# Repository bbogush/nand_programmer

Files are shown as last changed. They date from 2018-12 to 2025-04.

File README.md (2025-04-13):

# NANDO (NANDopen) programmer

## THE PROJECT IS NOT ACTIVELY SUPPORTED

## General
NANDO is open source NAND programmer based on STM32 processor. It supports parallel NAND and SPI flash programming.

PCB boards:

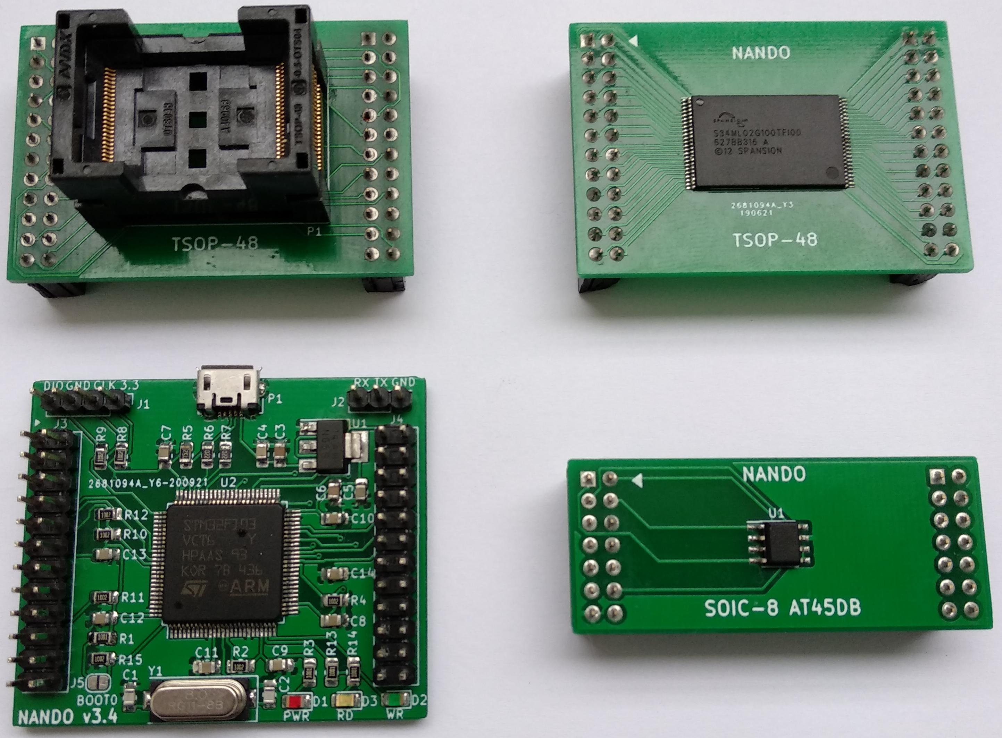
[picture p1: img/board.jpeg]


Application:

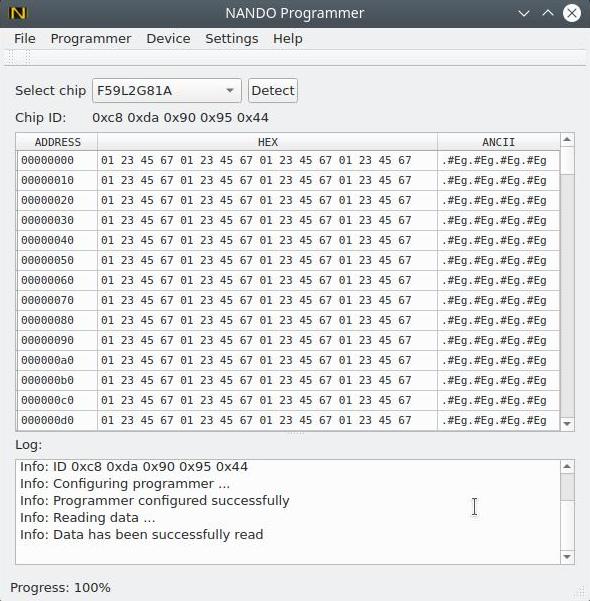
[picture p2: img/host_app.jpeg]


## Features
- USB interface
- PC client software for Linux & Windows.
- TSOP-48 socket adapter for NAND chip (compatible with TL866 adapter)
- TSOP-48 solder adapter for NAND chip
- 8 bit parallel NAND interface
- SPI interface
- 3.3V NAND power supply
- NAND read,write and erase support
- NAND read of chip ID support
- NAND read of bad blocks
- NAND bad block skip option
- NAND include spare area option
- Open KiCad PCB & Schematic
- Open source code
- Read & Write LEDs indication
- Extendable chip database
- Chip autodetection
- Firmware update

### Supported chips
#### Parallel NAND:
K9F2G08U0C, HY27US08121B, TC58NVG2S3E, F59L2G81A, MX30LF2G18AC and others.

See full list of supported chips [qt/nando_parallel_chip_db.csv](qt/nando_parallel_chip_db.csv)

#### SPI flash
AT45DB021D, MX25L8006E, W25Q16JV and others.

See full list of supported chips [qt/nando_spi_chip_db.csv](qt/nando_spi_chip_db.csv)

## Release binaries
You can download host application deb package for Ubuntu/Windows installer, firmware binary for
STM32, schematic and gerber files from <a href="https://drive.google.com/drive/folders/1d5hP6MKbkEBGQe_xIRl4-A5LPt_-9QIN">Google Driver</a>.

### License
In general the sorce code, PCB and schematic are under GPLv3 license but with limitations of:

firmware/libs/spl/CMSIS/License.doc

firmware/libs/spl/STM32_USB-FS-Device_Driver/ - http://www.st.com/software_license_agreement_liberty_v2

firmware/usb_cdc - http://www.st.com/software_license_agreement_liberty_v2

## WiKi
Check [WiKi](https://github.com/bbogush/nand_programmer/wiki) page for more information.

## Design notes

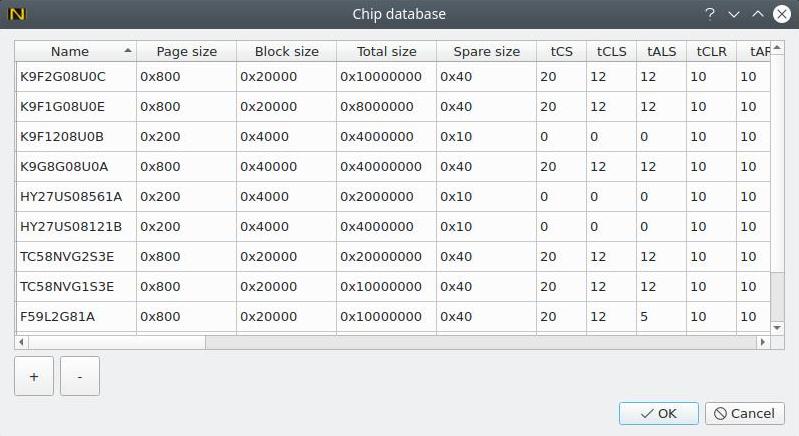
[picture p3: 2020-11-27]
img/chip_db_settings.jpeg

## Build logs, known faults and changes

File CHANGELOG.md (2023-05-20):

## [1.0.0] - 2018-11-25
- Initial release. Basic NAND operations support.
## [2.0.0] - 2019-03-09
### Added
- Reading of bad blocks.
- Skipping of bad blocks during read/write/erase.
- New PCB with smaller size, serial, LEDs and SWD instead of J-TAG.
- Firmware error codes.
- Firmware support of read and write LEDs.
### Fixed
- File-Save operation.
## [2.1.0] - 2019-04-16
### Added
- Chip database.
### Fixed
- Disconnect on the first connection.
## [2.2.0] - 2019-04-28
### Added
- Windows support.
- Added description of error codes.
### Fixed
- Fixed multiple prints of read ID completed log message.
## [2.3.0] - 2019-05-05
### Added
- Version support.
- Added progress indicator for erase, read and write commands.
### Fixed
- Fixed erase command.
- Fixed read bad block table command.
## [3.0.0] - 2019-09-26
### Added
- New board design. Support of internal clock in FW.
### Fixed
- Race condition in packet handling code.
## [3.1.0] - 2019-11-16
### Added
- Read including spare area
- Configuration of spare area size, number of column and row cycles, commands, bad block mark offset
- New chips support
- BOOT0 switch to PCB.
### Fixed
- Lost of some packets due to optimization.
## [3.2.0] - 2020-03-14
### Added
- Chip autodetection.
- Firmware update.
- Support of K9F1208U0B and F59L2G81A.
### Fixed
- Bad block table initialization.
- Read of bad blocks.
## [3.3.0] - 2020-08-31
### Added
- Single side components PCB 
- Support of HY27US08121B.
### Fixed
- Fixed read of bad blocks when read spare area command is available.
## [3.4.0] - 2020-12-22
### Added
SPI flash support.
SOIC-8 adapter for AT45DB.
New parallel NAND and SPI chips.
Boost library for serial port.
### Fixed
Fixed saving of settings.
Fixed lost of packets in Windows.
Fixed UI on Windows.
Schematic refactoring.
## [3.4.1] - 2021-02-14
### Added
Added NAND reset on init.
## [3.4.2] - 2021-03-17
### Added
Firmware compilation on Windows.
#### Fixed
Firmware update.
UI issues.
## [3.5.0] - 2023-05-20
### Added
Support of HW ECC.
Operation time estimate.
Serial port selector.
Progress indication.
Read/write to file instead of memory buffer.
Support of flash more then 4GB.
UI improvements for large buffers.
Custom read/write range.
Pinout table on PCB.
Verify operation.
### Fixed
NAND timings.
Synchronization issues.
Low write speed on Windows.

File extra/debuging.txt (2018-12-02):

debug (J-Link)
==============
1. Start openocd server:
# cd ~/dev/nand_programmer/nand_programmer/
# openocd -f extra/openocd.cfg
2. In new terminal connect to the server using telnet:
# telnet 127.0.0.1 4444
3. Reset board:
> reset halt
4. In new terminal start GDB:
# cd ~/dev/nand_programmer/
# compiler/gcc-arm-none-eabi-4_9-2015q1/bin/arm-none-eabi-gdb nand_programmer/firmware/obj/prog.elf
5. Connect to board:
>target remote localhost:3333
> b main
> continue

debug (ST-Link)
===============
1. Start st-util: 
# LD_LIBRARY_PATH=/usr/local/lib/ st-util
2. In new terminal start gdb
# cd ~/dev/nand_programmer/
# compiler/gcc-arm-none-eabi-4_9-2015q1/bin/arm-none-eabi-gdb nand_programmer/firmware/obj/prog.elf
> tar extended-remote :4242
> load
> b main
> continue

useful commands
===============
1. Disable pagination: 
> set pagination off
2. Print on breakpoint:
> break foo if x>0
     commands
     silent
     printf "x is %d\n",x
     cont
     end

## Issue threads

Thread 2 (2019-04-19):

USB device not found.

repairman0908, 2019-04-19:
serialprint:
NAND programmer ver: 2.1.0
JTAG init...done.
LED init...done.

I tested on win7 and showed unrecognized USB devices. What went wrong. Can you help me?

bbogush, 2019-04-19:
Hi repairman0908,
Do you have "USB init...done" and "CDC init..done" in the console log? If yes then USB initialization is done and probably you need driver for Windows. I will look for it and share a bit later.
In general the programmer should work out of the box on Ubuntu.

repairman0908, 2019-04-19:
Hello，bbogush，
Thank you for your reply！The following information is displayed only at power on or reset:
NAND programmer ver: 2.1.0
JTAG init...done.
LED init...done.
My circuit runs on the breadboard.

bbogush, 2019-04-19:
I can reproduce the same issue in 2 cases:
1. The driver is not installed. In this case you should see "STMMicroelectronics Virtual COM port" in Windows "Device Manager" as "Unknown device". I added official driver from STM to release folder  https://drive.google.com/drive/u/0/folders/1VHw-djlLal3cvaylapG-oUkLmzuEQM77
2. USB HW issue. The power connection is ok but no D+ & D-. You should check connection of mentioned lines from USB connector to MCU, also pull-up of D+ to 3.3V over 1.5R.

repairman0908, 2019-04-23:
Hi ,bbogush,
My board is working!   : )
I can read the chip ID.
But i received a error Msg : "programmer send error :104"  (when erase the chip.)

bbogush, 2019-04-24:
Hi,
Glad to hear you resolved USB issue.
The 104 error on erase means that programmer fails to read bad blocks from a NAND chip. Could you please provide more details about your setup?
In particular:
- Which NAND chip are you using? Is it  K9F2G08U0C?
- Which OS the program is running on? Is it Linux or Windows?

repairman0908, 2019-04-24:
Hi，bbogush,
Thank you for your patience.
1, the chip is  K9F1G08U0E.
2, The OS is Debian9 on virtual machine.
Do you have a windows program?

bbogush, 2019-04-24:
K9F1G08U0E is compatible with K9F2G08U0C which I've tested. So only "Size" should be adjusted in "Settings"->"Chip database" to 134217728 (128MB). Anyway the error is not related to this.
I am not sure it  works on virtual machine thereby better to check with normal OS. Currently there no version for Windows but I am working to provide it in the next release.
Usually the error 104 indicate HW issue. I would double check connection from MCU to NAND chip with multimeter according to schematic (test for continuity).
If you are using TSOP-48 socket it may be source of errors because it does not always provide reliable connection. A NAND chip should be clean and adjusted properly in socket.

bbogush, 2019-04-28:
Hi,
You can try initial version for Windows https://drive.google.com/drive/u/0/folders/1VHw-djlLal3cvaylapG-oUkLmzuEQM77. Windows 7/8 requires installation of driver. Also correct COM port need to be set in "Settings"->"Programmer".

bbogush, 2019-05-09:
Hi,
There are some pre-compiled binaries of CFE bootloader https://github.com/shsum/T3200M/tree/master/bcm963xx_router/targets/cfe. I am not sure which one is suitable for the router flash, maybe cfe63138rom.bin.
It looks the package contains only open source code so no guarantee it is compilable and run without proprietary part. I have tried as follows and it failed at some stage:
```
mkdir ~/dev
cd ~/dev/
git clone https://github.com/shsum/T3200M.git
sudo ln -s /home/<user>/dev/T3200M/toolchains /opt/toolchains
sudo ln -s /home/<user>/dev/T3200M/bcm963xx_router /opt/bcm963xx_router
 sudo apt-get install liblzo2-dev uuid-dev
cd ~/dev/T3200M/bcm963xx_router
make --trace PROFILE=963138BGW SHELL=/bin/bash
```

repairman0908, 2019-05-10:
Thank you for your help, I have tried all the CFE, they can not start my router.
There is also source code on the Netgear website. I don't know what is different. here[https://www.downloads.netgear.com/files/GDC/2649_GPLv1.html](url) Ctrl+f search v7610 can be found it.
Thank you very much!

bbogush, 2019-05-11:
Hi,
There is open source package for V7610.  The previous T3200M package was for different router based on the same Broadcom platform. It can be compiled similar to T3200M
"make PROFILE=V7610_TR181 SHELL=/bin/bash" but it also has compilation issues. Even if compiled I think it will not be functional because of missing proprietary code. There are also binaries for cfe you can try. You should have serial console connected to the router to see they work.
Also one of the methods is to clone flash from the same router.

repairman0908, 2019-05-12:
Hi,
Thanks for your advice. I used a serial console, but no information was printed. Because I can't find the same router, I just thought of compiling the source code. Anyway, thank you very much for your help.

bbogush, 2019-06-02:
As no other issues with the programmer I am closing it. If you have any other questions, please feel free to ask.

Closed 2019-06-02.

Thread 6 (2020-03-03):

STM32F103C8T6 porting

alexgrach, 2020-03-03:
Is it possible to port you project from STM32F103VCT6 to STM32F103C8T6?

bbogush, 2020-03-03:
The project requires FSMC (flexible static memory controller) which is embedded in the STM32F103xC, STM32F103xD and STM32F103xE family. Unfortunately, STM32F103C8T6 is missing this feature.

Closed 2020-03-03.

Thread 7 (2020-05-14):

Ask some questions

leovs, 2020-05-14:
Serial info：

NAND programmer ver: 3.1.0
JTAG init...done.
LED init...done.
USB init...done.
CDC init...done.
ERROR: NAND read bad block info error at 0x0

chip：ESMT  F59L2G81A

bbogush, 2020-05-14:
This error in most cases means bad hardware connection with NAND or NAND is broken. The sockets adapters are not usually provide reliable connection. It requires few tries to properly put NAND. To be sure I use soldering adapters. After soldering the adapter with NAND needs to be carefully cleaned from flux.
You can also try Settings -> Programmer -> Uncheck "Skip bad block" option in order to check that chip cannot be read.
Are you able to read correct chip ID - c8 da 90 95 44 ?
Have you compiled the latest source or used 3.1.0 release binaries?

leovs, 2020-05-14:
Thank you for your reply
Binaries used in version 3.1.0
chip ID ：0XFD 0XFD 0XFD 0XFD

leovs, 2020-05-14:
Nando running Windows 10
The default chip database does not have f59l2g81a
add :
F59L2G81A 0x800 0x20000 0x10000000 0x40 20 12 5 10 10 12 12 12 5 5 5 25 25 20 3 2 0x0 0x30 - 0x90 0xff 0x80 0x10 0x60 0xd0 0x70 0

leovs, 2020-05-14:
Uncheck "Skip bad block" option

info:"Bad block at 0x0XXXXXXXXXX size 0x00020000"
more
All failed

bbogush, 2020-05-14:
The latest code contains fixes and default support of f59l2g81a. I will make new release today so you can check.

bbogush, 2020-05-14:
The new 3.2.0 release of stm firmware and windows software is available for download.  Although SW contains fixes the chip ID 0XFD 0XFD 0XFD 0XFD in 99% shows NAND connection problem with programmer.

leovs, 2020-05-15:
Thank you
still:
Error: "Programmer sent error: (104) Failed to read chip"

maybe NAND connection problem，I'll check again

leovs, 2020-05-19:
It seems that the data can be read normally, but I don't know if it works correctly

Info: Connected to programmer
Info: Firmware version:  3.2.0
Info: Detecting chip ...
Info: ID 0xE8 0xFA 0xB0 0xB5 0x64
Info: Chip not found in database
Info: Configuring programmer ...
Info: Programmer configured successfully
Info: Reading data ...
Info: "Skipped bad block at 0x00000000 size 0x00020000"

bbogush, 2020-05-19:
There still problem with connection, the ID should be
0xC8 0xDA 0x90 0x95 0x44
but is
0xE8 0xFA 0xB0 0xB5 0x64
some pins are connected correctly but others not
0xC8 - 0b11001000
0xE8 - 0b11101000
Please check FSMC_D0 - FSMC_D7

bbogush, 2020-06-08:
Closing. Please reopen the issue if you still have any questions.
Regards

Closed 2020-06-08.

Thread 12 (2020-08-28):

Can you add support for spi nor flash chip？

jiuweiljp, 2020-08-28:
In the project https://github.com/dword1511/stm32-vserprog (libcopencm3) use STM32F103C8T6 PA4,5,6,7 to support spi nor flash

jiuweiljp, 2020-08-28:
old project https://github.com/dword1511/serprog-stm32vcp

bbogush, 2020-08-29:
Hi,
Thank you for idea. It is possible, but currently SPI pins are not routed. So this requires redesign of PCB. I will add it to work backlog but not sure it can be done soon.

Regards

jiuweiljp, 2020-08-31:
Thx, this would be really cool

jiuweiljp, 2020-08-31:
Thx, this would be really cool

alexgrach, 2020-12-07:
It would be nice to have I2C EEPROM support too...

bbogush, 2020-12-22:
Closing issue. SPI support added in version 3.4.0. I2C support may be added in next releases.

Closed 2020-12-22.

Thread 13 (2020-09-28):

Can show Effective(available) com port and put port select and connect  at  main window?

kuangjunchaos, 2020-09-28:
Can show Effective(available) com port and put port select and connect  at  main window?

port select         buttom
Com60 |             connect!
            V

bbogush, 2020-10-03:
Thank for idea, but I don't want to overload main window with multiple settings. This is not user friendly. The serial port should be configured once and usually it should be the same on the next connection. Currently settings are not saved but when this will be implemented selection of port should not be a problem.

Closed 2020-10-10.

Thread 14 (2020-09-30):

Reset button

alexgrach, 2020-09-30:
It would be nice to have reset button. I have to use a wire to reset before flashing over SWD by st-link.

bbogush, 2020-10-03:
HW reset button is rarely used and can be replaced by cable unplug-plug action. Thereby I would not add additional component to PCB design which may increase its size.

alexgrach, 2020-10-07:
I've added NRTS just like BOOT0 and made some changes in schematics to make it look better and readable.
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
[nand_programmator.zip](https://github.com/bbogush/nand_programmer/files/5343890/nand_programmator.zip)

Closed 2020-10-03.

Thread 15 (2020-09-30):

Windows binary version error

alexgrach, 2020-09-30:
I've just downloaded windows installer from google drive nando-3.3.0 folder. Help->About NANDO shows Version: 3.2.0
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

bbogush, 2020-10-03:
Updated. Thank you for notification.

Closed 2020-10-03.

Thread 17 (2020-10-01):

Error detecting TC58NVG1S3E

alexgrach, 2020-10-01:
I've tried to read 2 different NAND ICs. No success.

Info: Connected to programmer
Info: Firmware version:  3.3.0
Info: Detecting chip ...
Info: ID 0x8F 0x8F 0x8F 0x8F 0x8F
Info: Chip not found in database
Info: Detecting chip ...
Info: ID 0x8F 0x8F 0x8F 0x8F 0x8F
Info: Chip not found in database

bbogush, 2020-10-03:
In 99% it is hardware problem:
- no connection between STM and NAND, for example, some pins of STM are not soldered, NAND pins are not soldered or bad connection in TSOP socket.
- stray capacitance if flux is not cleaned well after soldering.

alexgrach, 2020-10-06:
I've resoldered my chip and it worked, thank you!
chip_db to support this IC:
`
TC58NVG1S3E, 2048, 131072, 268435456, 64, 20, 12, 12, 10, 10, 12, 12, 12, 5, 5, 5, 25, 25, 20, 3, 2, 0, 48, -, 144, 255, 128, 16, 96, 208, 112, 0, 152, 218, 144, 21, 118
`

bbogush, 2020-10-10:
Glad to hear it works for you.
Thank you for new chip. I've added it database.

Closed 2020-10-10.

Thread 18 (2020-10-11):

Reset pad

alexgrach, 2020-10-11:
I've added NRTS just like BOOT0 and made some changes in schematics to make it look better and readable.
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
[nand_programmator.zip](https://github.com/bbogush/nand_programmer/files/5343890/nand_programmator.zip)

_Originally posted by @alexgrach in https://github.com/bbogush/nand_programmer/issues/14#issuecomment-705198990_

bbogush, 2020-10-11:
I appreciate your contribution. The change looks really nice but currently I have some doubts whether to include it. The reason is that most programmers don't provide HW reset and I don't see use cases for it because this can be done by power off-on.

alexgrach, 2020-10-11:
I see. It seems to me that reset is needed when you update programmer FW from previous version (from 3.1 to 3.3 in my case). With new IC st-link does not ask to boot under reset. If you do like schematics I can delete reset pad (or you can do it) pcb won't suffer.

alexgrach, 2020-10-11:
[nand_programmator.sch.zip](https://github.com/bbogush/nand_programmer/files/5361173/nand_programmator.sch.zip)

bbogush, 2020-10-11:
I think now I understand. Sometime STM cannot be programmed because it has disabled SWD pins for some reason and the only way is too "connect under reset". The RST pads are required. Would you like to create git pull request with your original changes so you will be mentioned as project contributor by github? If not I can apply changes.

alexgrach, 2020-10-11:
I've never done this before but I'll try. #19

bbogush, 2020-10-12:
The changes are merged. Thank you for contribution.

Closed 2020-10-12.

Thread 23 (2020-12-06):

Can you add support for STM32F103ZET6

mlpzaq9998, 2020-12-06:
[1、STM32F103ZE核心板--原理图-1807M.pdf](https://github.com/bbogush/nand_programmer/files/5648222/1.STM32F103ZE.--.-1807M.pdf)

mlpzaq9998, 2020-12-06:
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

Run NANDO to display the （112）wrong data length

mlpzaq9998, 2020-12-06:
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

bbogush, 2020-12-06:
Hello,

I see STM32F103ZET6 should be compatible with NANDO's STM32F103VCT6.
Regarding error, the version of firmware was read correctly so USB communication works. The reason of error is that NANDO  firmware received not enough or to many data in configuration command. The UART log can show more information. Are you using released firmware and PC program provided in GoogleDriver?

mlpzaq9998, 2020-12-06:
using released PC program provided in GoogleDriver，The firmware is GitHub
How to eliminate errors?

bbogush, 2020-12-06:
The firmware and PC program should be the same version because communication protocol sometimes changes. So you should use the released PC program and firmware from google driver or checkout git tag of the same version, i.e, git checkout 3.3.0.

mlpzaq9998, 2020-12-06:
Use the same version of the checkout git tag，NANDO display

Info: Connected to programmer
Info: Firmware version: 3.3.0
Info: Detecting chip ...
Info: ID 0x8F 0x8F 0x8F 0x8F 0x8F
Info: Chip not found in database
Info: Detecting chip ...
Info: ID 0x8F 0x8F 0x8F 0x8F 0x8F
Info: Chip not found in database

It should be a hardware problem

mlpzaq9998, 2020-12-06:
Can the new firmware include HEX

bbogush, 2020-12-06:
0x8F 0x8F 0x8F 0x8F 0x8F pattern shows hardware problem - unconnected pins or high stray capacitance.

Yes, hex will be included, also it can be received by following conversion, but haven't tried if it works.
../../compiler/gcc-arm-none-eabi-4_9-2015q1/bin/arm-none-eabi-objcopy --input-target=binary --output-target=ihex obj/fw.bin obj/fw.hex

bbogush, 2020-12-22:
Closing old issues. Please reopen if you still have questions.

Closed 2020-12-22.

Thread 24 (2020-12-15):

How to flash firmware using usb serial cable?

bra1nslayer, 2020-12-15:
Hi,
I have FT232RL same board as here: https://www.sparkfun.com/products/12731
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

Is it possible to flash fimware nando_fw_v3_3_0.bin via arduino ide?Or another program suggestions?
Thanks in advance, very useful programmer btw.

bbogush, 2020-12-15:
Hi,
The best option is to use stlink programmer. You can try to use build-in USB/USART bootloader. For this you need to install stm32 tool https://www.st.com/en/development-tools/stm32cubeprog.html# and after that power on board with connected BOOT0 pins to load internal DFU bootloader. Though, I've just tried and this method for some reason does not work for me, device is not recognized by Windows.

bra1nslayer, 2020-12-16:
Hi,
Uploaded firmware using serial cable but neither windows and linux recognizes as usb device.For firmware upload i have used stm32cube for windows and stm32flash for linux.Writing firmware was successful but as i said it cannot detect as usb device.Here is some info:
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

```

[  409.635435] usb 1-4: new full-speed USB device number 2 using xhci_hcd
[  409.763420] usb 1-4: device descriptor read/64, error -71
[  409.999461] usb 1-4: device descriptor read/64, error -71
[  410.235499] usb 1-4: new full-speed USB device number 3 using xhci_hcd
[  410.363415] usb 1-4: device descriptor read/64, error -71
[  410.599495] usb 1-4: device descriptor read/64, error -71
[  410.707509] usb usb1-port4: attempt power cycle
[  411.363359] usb 1-4: new full-speed USB device number 4 using xhci_hcd
[  411.363514] usb 1-4: Device not responding to setup address.
[  411.571534] usb 1-4: Device not responding to setup address.
[  411.779727] usb 1-4: device not accepting address 4, error -71
[  411.911830] usb 1-4: new full-speed USB device number 5 using xhci_hcd
[  411.911947] usb 1-4: Device not responding to setup address.
[  412.120132] usb 1-4: Device not responding to setup address.
[  412.327371] usb 1-4: device not accepting address 5, error -71
[  412.327456] usb usb1-port4: unable to enumerate USB device
```
```
sudo stm32flash -w nando_fw_v3_3_0.bin -v -g 0x0 /dev/ttyUSB0

stm32flash 0.5

http://stm32flash.sourceforge.net/

Using Parser : Raw BINARY
Interface serial_posix: 57600 8E1
Version      : 0x22
Option 1     : 0x00
Option 2     : 0x00
Device ID    : 0x0414 (STM32F10xxx High-density)
- RAM        : 64KiB  (512b reserved by bootloader)
- Flash      : 512KiB (size first sector: 2x2048)
- Option RAM : 16b
- System RAM : 2KiB
Write to memory
Erasing memory
Wrote and verified address 0x08040000 (100.00%) Done.

Starting execution at address 0x08000000... done.
```
Thanks for help.

bbogush, 2020-12-17:
Hi,
The NANDO fw should print logs via USART1, so you can check if fw was written successfully.
Unfortunately cannot help with STM tool.

bra1nslayer, 2020-12-17:
Hi,
Just managed to work.I think microcontroller is executing code slow and failing to respond host pc.In meantime host was already giving up initing usb.
After flashing firmware i executed:
```
sudo stm32flash -g 0x08000000 /dev/ttyUSB0

stm32flash 0.5

http://stm32flash.sourceforge.net/

Interface serial_posix: 57600 8E1
Version      : 0x22
Option 1     : 0x00
Option 2     : 0x00
Device ID    : 0x0414 (STM32F10xxx High-density)
- RAM        : 64KiB  (512b reserved by bootloader)
- Flash      : 512KiB (size first sector: 2x2048)
- Option RAM : 16b
- System RAM : 2KiB

Starting execution at address 0x08000000... done.
```
Then dmesg shows usb is working properly.
```
[ 4287.735237] usb 1-4: USB disconnect, device number 103
[ 4292.787484] usb 1-4: new full-speed USB device number 104 using xhci_hcd
[ 4292.965180] usb 1-4: New USB device found, idVendor=0483, idProduct=5740, bcdDevice= 2.00
[ 4292.965185] usb 1-4: New USB device strings: Mfr=1, Product=2, SerialNumber=3
[ 4292.965188] usb 1-4: Product: STM32 Virtual COM Port
[ 4292.965190] usb 1-4: Manufacturer: STMicroelectronics
[ 4292.965192] usb 1-4: SerialNumber: 56F967703335
[ 4293.029379] cdc_acm 1-4:1.0: ttyACM0: USB ACM device
```
Entered nando gui:
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
But after powercycling i always have to execute "sudo stm32flash -g 0x08000000 /dev/ttyUSB0 "
Also tried to flash fimrware from gui app.Same behavior.
Tried powering up board externally first then connected 2 usb pins sometimes works.
BTW:What does 0xEF 0xEF means?
Thanks.

bra1nslayer, 2020-12-17:
Tried another chip id detection seems work:
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

bbogush, 2020-12-17:
Hi,
It looks that fw is loaded from RAM, not flash. Have you removed BOOT0 pins connection?
ID 0xEF ...means that NAND memory is not connected or some high stray capacitance (usually due to not cleaned flux).

bra1nslayer, 2020-12-17:
Yes i have removed BOOT0 after flashing firmware.Same behavior if i don't execute  stm32flash -g 0x08000000 it doesn't recognize usb.I didn't specify filename in ""sudo stm32flash -g 0x08000000 /dev/ttyUSB0 "" i think it runs on flash not RAM.As i said "Also tried to flash fimrware from gui app.Same behavior." i think it proves i doesn't run on RAM right?I have never used STM32 before so i may be mistaken.

bbogush, 2020-12-17:
Yes, the firmware is written to flash. STM has different boot modes - from flash/ram. I've just had assumption that for some reason it starts code execution from RAM and ```sudo stm32flash -g 0x08000000 /dev/ttyUSB0``` makes it execute code from flash. If you can see serial port logs from firmware before command than it is not the case. It can be USB issue.

bra1nslayer, 2020-12-17:
Ok i see now, let me explain step by step what i have done:

1-Attached usb serial to board
2-Executed putty in /dev/ttyUSB0
3-Powered on board (Plugged in USB cable)
4-No output from putty
5-Executed `sudo stm32flash -g 0x08000000 /dev/ttyUSB0` on linux terminal
6-This serial output from putty:
```

Start application: 0

NAND programmer ver: 3.3.0
JTAG init...done.
LED init...done.
```

Is this an indication of my usb connection is bad?

Thanks for helping.

bbogush, 2020-12-17:
3-Powered on board (Plugged in USB cable) - After this step there should be logs so probably STM boots from RAM/System memory.
LED init...done. - there should be other logs after this, so there is also usb problem but maybe it caused by this switching from RAM boot to flash boot.
You can check boot settings according to stm manual
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

bra1nslayer, 2020-12-17:
I think i must use st-link since i don't have one, will order it.Is type works fine?
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

bbogush, 2020-12-17:
V2 should be ok.

bra1nslayer, 2020-12-17:
Thanks, just bought it.Will post results.

bra1nslayer, 2020-12-21:
St-link didn't arrived yet but i managed to read a Hynix HY27US08281A, here is the parameters i have used:
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

In csv format:HY27US08281A, 512, 16384, 16777216, 16, 0, 0, 0, 10, 10, 35, 25, 20, 10, 10, 10, 50, 50, 30, 2, 1, 0, -, 80, 144, 255, 128, 16, 96, 208, 112, 0, 173, 115, -, -, -
In gui format:HY27US08281A 0x200 0x4000 0x1000000 0x10 0 0 0 10 10 35 25 20 10 10 10 50 50 30 2 1 0x0 - 0x50 0x90 0xff 0x80 0x10 0x60 0xd0 0x70 0 0xad 0x73 - - -
Could you please add to database?

bbogush, 2020-12-21:
Hi,
I've added HY27US08281A to the BD.
HY27US08281A has only two bytes of ID but programmer tries to read five for all chips, thereby ID is repeating. It is ok, only minor UI presentation issue.
The case looks great. Thanks!
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
bbogush, 2021-01-08:
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

According to datasheet HY27US08281A and HY27US08561A have different IDs so maybe ID was not correctly read.
HY27US08561A - ADh 75h
HY27US08281A - ADh 73h

bbogush, 2021-01-08:
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

Pins do not have pull-up/down so when unconnected their value undetermined.

bbogush, 2021-01-09:
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

Thank you for pointing this out. I was looking for this document to check.

danyhm, 2021-01-09:
I'm having problems reading a micron NAND flash

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

the part number is MT29F1G08ABAD which is very similar to MT29F4G08ABAD in it's parameters.

I can't get the programmer to detect the chip correctly. it's showing the above results

how can I start debugging this?

danyhm, 2021-01-09:
in fact having the NAND flash in the adapter or not doesn't make a difference in the results.

bbogush, 2021-01-09:
> also the pcb design is not the best. R2 is chosen as 10k which is too much and my board keeps resetting. i changed it to 1.5k and now the reset problem is solved

The general problems are:
- TSOP-48 socket does not provide reliable connection for unsoldered NAND because pins are not even so advise is use "soldering adapters", try to adjust NAND in socket to see the difference in read ID.
- no connection between MCU and adapter/NAND, try to check connections by tester.
- stay capacitance, make sure no flux leftovers after soldering.

danyhm, 2021-01-09:
after connecting and disconnecting all the wires I could get the first byte correct

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

but still no success

danyhm, 2021-01-09:
ok i managed to get it working. it seems to be a software issue.

I added the new chip in the parallel database and configured it according to the datasheet which is exactly the same as MT29F4G08ABAD except the chip ID is `0x2c 0xf1 0x80 0x95 0x02` and the total size is `0x8000000`

normally clicking detect gives the wrong output like
```
Info: Detecting chip ...
Info: ID 0x2c 0x01 0x02 0x03 0x04
Info: ID 0xff 0xff 0xff 0xff 0x00
```
but if I select the chip manually and then click read , the chip is read. afterwards clicking detect gives the correct result
also when clicking read sometimes it gives the error `Error: Chip size is not set` while it actually is set in the database. but changing the totalsize to something else then solves the error and the chip can be read.

i hope I was clear in explaining the bug

danyhm, 2021-01-11:
just a question out of the topic.

I'm trying to restore my scope which firmware I corrupted by accident. I'm programming the bootloader after erasing the first block but after soldering the Nand it still doesn't boot. what could I be doing wrong? could it have to do something with the OOB data part? should that be cleared too ?

bbogush, 2021-01-11:
> just a question out of the topic.
>
> I'm trying to restore my scope which firmware I corrupted by accident. I'm programming the bootloader after erasing the first block but after soldering the Nand it still doesn't boot. what could I be doing wrong? could it have to do something with the OOB data part? should that be cleared too ?

I don't have MT29 to check but other chips work correctly. Have you verified that write was successful by comparing write and read dump? I still recommend to make soldering adapter to avoid any hw issues. OOB data should be already cleared by block erase because there is no separate command for OOB erase. The best approach to recover bootloader is to have dump from working device together with OOB.

danyhm, 2021-01-11:
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

yes I compared the written data with another read and the write has been successful. I have a dump of a working device but it doesn't have OOB data. I'm scratching my head here as logically it should work, but it's not working. :(

danyhm, 2021-01-12:
I think i have a lead.

The Zynq 7000 series in my oscope uses internal ECC feature of the Nand flash.
Since I'm programming with ECC disabled (default on POR) the OOB data doesn't include the parity bits generated by internal ECC and that might be why the bootloader is failing.

Nando software doesn't support enabling internal ECC yet , so I have 2 options
1- Implement the ECC feature my self. but I'm not familiar with the code flow and it takes a lot of time.
2- manually calculate the ECC parity bits and add them in OOB data and program with those.

do you know how the parity Bits are calculated ?
it would be very neat if you could add a custom command window where one can send and receive custom data to the chips.

bbogush, 2021-01-12:
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

Good catch! I cannot help with ECC calculation but it's required feature and will think how to add it future.

danyhm, 2021-01-12:
thank you very much,
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

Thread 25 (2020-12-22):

Can you add support for stm32 blue pill ?

ellissonmax, 2020-12-22:
I am trying read/write on hy27uf084g2b with a stm32 (Blue Pill).

ellissonmax, 2020-12-22:
> stm32flash -g 0x8000000 -w nando_fw_v3_4_0.bin /dev/ttyUSB0

 stm32flash 0.5

 http://stm32flash.sourceforge.net/

 Using Parser : Raw BINARY
 Interface serial_posix: 57600 8E1
 Version      : 0x22
 Option 1     : 0x00
 Option 2     : 0x00
 Device ID    : 0x0410 (STM32F10xxx Medium-density)
 - RAM        : 20KiB  (512b reserved by bootloader)
 - Flash      : 128KiB (size first sector: 4x1024)
 - Option RAM : 16b
 - System RAM : 2KiB
 Write to memory
 Erasing memory
 Wrote address 0x08020000 (50.00%) Done.

 Starting execution at address 0x08000000... done.

Closed 2020-12-22.

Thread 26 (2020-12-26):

Does it support STM32F407?

quanghau113, 2020-12-26:
I have a STM32F407 board. Can I make it work on STM32F4 series?

bbogush, 2020-12-26:
STM32F407 supports all required hardware features (FSMC, SPI, USB) but software supports only STM32F103 family (256-512MB flash).

enilfodne, 2021-01-22:
On that note, would you be willing to merge a PR for STM32F2/4 support?

It's a big PR (very hard to split up in smaller commits) and the scope is software-only (i.e. no new schematics or part-numbers).

bbogush, 2021-01-27:
> On that note, would you be willing to merge a PR for STM32F2/4 support?
>
> It's a big PR (very hard to split up in smaller commits) and the scope is software-only (i.e. no new schematics or part-numbers).

I suggest to merge support of STM32F4 to separate branch such as support_stm32f4 and it may be integrated to master in future.

bbogush, 2021-02-28:
Closing old issues. Please reopen if open questions remain.

Closed 2021-02-28.

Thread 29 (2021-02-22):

The Qt host application will not compile on gcc9 and newer

nQ1PX, 2021-02-22:
Similar to #8 and still 100% reproducible on my system on the latest commit. Additionally, removing `-Wextra -Werror` in `qt.pro` has no effect, as you can see they still show up in the output. I have tested gcc6 all the way to gcc10, gcc8 is the last version that will build the host application.

```
$ make
/../lib64/qt5/bin/uic main_window.ui -o ../build/ui/ui_main_window.h
/../lib64/qt5/bin/uic parallel_chip_db_dialog.ui -o ../build/ui/ui_parallel_chip_db_dialog.h
/../lib64/qt5/bin/uic settings_programmer_dialog.ui -o ../build/ui/ui_settings_programmer_dialog.h
/../lib64/qt5/bin/uic about_dialog.ui -o ../build/ui/ui_about_dialog.h
/../lib64/qt5/bin/uic firmware_update_dialog.ui -o ../build/ui/ui_firmware_update_dialog.h
/../lib64/qt5/bin/uic spi_chip_db_dialog.ui -o ../build/ui/ui_spi_chip_db_dialog.h
g++ -c -pipe -std=c++11 -O2 -Wall -Wextra -D_REENTRANT -fPIC -DQT_NO_DEBUG -DQT_WIDGETS_LIB -DQT_GUI_LIB -DQT_CORE_LIB -I. -I/usr/include/qt5 -I/usr/include/qt5/QtWidgets -I/usr/include/qt5/QtGui -I/usr/include/qt5/QtCore -I../build/moc -I../build/ui -I/../lib64/qt5/mkspecs/linux-g++ -o ../build/o/unix/main.o main.cpp
In file included from writer.h:9,
                 from programmer.h:12,
                 from main_window.h:9,
                 from main.cpp:6:
cmd.h:122:13: error: flexible array member ‘RespHeader::data’ not at end of ‘struct<unnamed>’
  122 |     uint8_t data[];
      |             ^~~~
cmd.h:128:15: note: next member ‘FwVersion <unnamed struct>::version’ declared here
  128 |     FwVersion version;
      |               ^~~~~~~
cmd.h:126:1: note: in the definition of ‘struct<unnamed>’
  126 | {
      | ^
cmd.h:122:13: error: flexible array member ‘RespHeader::data’ not at end of ‘struct<unnamed>’
  122 |     uint8_t data[];
      |             ^~~~
cmd.h:134:12: note: next member ‘ChipId <unnamed struct>::nandId’ declared here
  134 |     ChipId nandId;
      |            ^~~~~~
cmd.h:132:1: note: in the definition of ‘struct<unnamed>’
  132 | {
      | ^
cmd.h:122:13: error: flexible array member ‘RespHeader::data’ not at end of ‘struct<unnamed>’
  122 |     uint8_t data[];
      |             ^~~~
cmd.h:140:14: note: next member ‘uint32_t <unnamed struct>::addr’ declared here
  140 |     uint32_t addr;
      |              ^~~~
cmd.h:138:1: note: in the definition of ‘struct<unnamed>’
  138 | {
      | ^
cmd.h:122:13: error: flexible array member ‘RespHeader::data’ not at end of ‘struct<unnamed>’
  122 |     uint8_t data[];
      |             ^~~~
cmd.h:147:14: note: next member ‘uint32_t <unnamed struct>::ackBytes’ declared here
  147 |     uint32_t ackBytes;
      |              ^~~~~~~~
cmd.h:145:1: note: in the definition of ‘struct<unnamed>’
  145 | {
      | ^
cmd.h:122:13: error: flexible array member ‘RespHeader::data’ not at end of ‘struct<unnamed>’
  122 |     uint8_t data[];
      |             ^~~~
cmd.h:153:13: note: next member ‘uint8_t <unnamed struct>::errCode’ declared here
  153 |     uint8_t errCode;
      |             ^~~~~~~
cmd.h:151:1: note: in the definition of ‘struct<unnamed>’
  151 | {
      | ^
cmd.h:122:13: error: flexible array member ‘RespHeader::data’ not at end of ‘struct<unnamed>’
  122 |     uint8_t data[];
      |             ^~~~
cmd.h:159:14: note: next member ‘uint32_t <unnamed struct>::progress’ declared here
  159 |     uint32_t progress;
      |              ^~~~~~~~
cmd.h:157:1: note: in the definition of ‘struct<unnamed>’
  157 | {
      | ^
make: *** [Makefile:639: ../build/o/unix/main.o] Error 1
```

bbogush, 2021-02-28:
Fixed, removed flexible array usage.

Closed 2021-02-28.

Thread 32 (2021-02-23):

Potential issues on bad block handling

nQ1PX, 2021-02-23:
I was testing a few chips I happened to have on hand and preparing to send in a PR, but I noticed the current bad block handling strategy might not be the best here. Suppose I have a 128MB chip with 4 bad blocks, the read result does not correlate to the actual data on flash, as I have 0x80000 of 0x00 at the very end of the buffer.

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

And if I load a 128MB file, the write operation will cause the program to error out too, because my file was "too large" if you subtract the 4 bad blocks.
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

Usually the "skip bad block" option in other things I've seen just increments the counter and skips the actual r/w operation, so fill bad blocks with FF in buffer for read and skipping writing/erasing entirely (discard data for bad blocks). This way we can still have a consistent, whole 128MB file without having to worry about manually recording the offsets and mangling with the binary with a hex editor to insert/remove blank bits.

bbogush, 2021-03-13:
Fixed. Skipped bad block are not included in read buffer.

Closed 2021-03-13.

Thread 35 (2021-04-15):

Fix ASCII typo (?) in GUI

donnm, 2021-04-15:
The third column in the GUI shows printable ASCII bytes, but is named ANCII. I assume this is a typo?

bbogush, 2021-04-16:
Thank you for noticing. Fixed.

Closed 2021-04-16.

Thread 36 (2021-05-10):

Replace R3, R13, R14 with lower value resistors

donnm, 2021-05-10:
The LEDs are quite dim under normal ambient room lighting. I have built a few of these boards now and through experimentation found that from 100R to 330R are a more suitable brightness. For what its worth I spec'd the LEDs directly from the part numbers in the BOM.

You might consider replacing R3, R13, and R14 with lower value resistors in the HW design.

bbogush, 2021-06-21:
Thanks for sharing. I will consider changes.

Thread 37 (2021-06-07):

Parallel NOR flash support?

donnm, 2021-06-07:
I started adding support for M29W640GB in the chip database before realising it was NOR flash (couldn't find all the timing info in the datasheet). Does this have any chance of working?

bbogush, 2021-06-08:
Currently NOR is not supported, I think it will not work because NOR uses different programming approach.

gitercn, 2021-06-20:
I'm also looking for a programmer for Spansion S29 NOR FLASH programmer (TSOP56). Is there any open source NOR programmers? Could this project add NOR support?

bbogush, 2021-06-21:
> I'm also looking for a programmer for Spansion S29 NOR FLASH programmer (TSOP56). Is there any open source NOR programmers? Could this project add NOR support?

I haven't seen open source NOR programmers. This project can be extended to support NOR and STM chip has support of it. I'm not sure when it will be added because development requires some time.

donnm, 2021-06-21:
There's this, an Arduino Mega connected to a 32 pin PDIP NOR flash: https://mint64.home.blog/2018/07/29/parallel-nor-flash-eeprom-programmer-using-an-arduino-part-1-the-sst39sf040-and-planning/

Part 2 has the Arduino sketch code: https://mint64.home.blog/2018/07/30/parallel-nor-flash-eeprom-programmer-using-an-arduino-part-2-arduino-code-and-serial-comms/

Closed 2023-05-23.

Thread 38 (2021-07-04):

Porting programmer to raspberry

hamid1920, 2021-07-04:
Is it possible to add support for raspberry boards
It has all needed pins so there is no need to build a programmer pcb from scratch

bbogush, 2021-07-04:
MCU should have some memory interface as FSMC in STM. Otherwise read/write of NAND using GPIO bit-banging will take hours. I see raspberry pi has SMI (secondary memory interface). Need to do proof of concept to see whether it is suitable.

Closed 2023-05-23.

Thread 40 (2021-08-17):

TSOP56 NAND Compatibility

kooroshi60, 2021-08-17:
Does NANDO support 56 pin NAND memories? If so, how is the pin assignment on the 48pin socket ?
I would be happy to design and share the PCB for such an adapter if it is possible.

bbogush, 2021-08-21:
TSOP-56 is usually used by NOR memories. I've checked few websites with parts and haven't found 56 pin NAND. NOR currently is not supported because it requires change of MCU to another model with more pins.

kooroshi60, 2021-08-22:
Thank you so much for your informative answer.

Closed 2021-08-22.

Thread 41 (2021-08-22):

NANDO Eagle PCB (48pin ZIF)

kooroshi60, 2021-08-22:
Here is an another variant of PCB for this great project. (Eagle 9 Format + PDF)
-Since the track clearance is .15mm, this PCB has to be made with Photo Resist film technic.
Toner transfer method is not precise enough.
-This is a double layer PCB so don't forget to solder VIAs.
-All the components except the USB connector are SMD.
-You can find the value of the components in the Eagle files.
-You can either use a 48pin ZIF IC Socket or 4 rows of pin headers in order to support 7.2mm and 15.24mm ZIFs.
-There are 18 pins of the socket which need a VIA wire. Other pins of ZIF socket and the USB connector are routed from Bottom layer.
[NANDO Bottom.pdf](https://github.com/bbogush/nand_programmer/files/7027975/NANDO.Bottom.pdf)
[NANDO TOP.pdf](https://github.com/bbogush/nand_programmer/files/7027976/NANDO.TOP.pdf)
[Nando_ZIF48_USBb.zip](https://github.com/bbogush/nand_programmer/files/7027980/Nando_ZIF48_USBb.zip)

bbogush, 2021-08-28:
Thanks for sharing ZIF schematic.
VET6 and VDT6 should also work, the redundant memory will not be used.

kooroshi60, 2021-12-24:
And here is a picture of completed Nando programmer. Many thanks to Mr. Bogus
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
h

bbogush, 2021-12-25:
Very nice PCB. Thank you!

ucsoom, 2023-03-19:
I created a programmer like yours based on your PCB file. The trouble now is that I have searched the internet for a suitable hex file for this programmer. Could you please send the hex file of your programmer? My email address is 401707682@qq.com

ucsoom, 2023-03-19:
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

bbogush, 2023-03-19:
@ucsoom all hex files are located on Google driver https://drive.google.com/drive/folders/1AGWV5_WANd6tItfXJFq4AlQePkRsusNU

ucsoom, 2023-03-20:
Thank you! Open Google's website here in China.

ucsoom, 2023-03-20:
Thank you! China has banned Google.

ucsoom, 2023-03-20:
The website you sent cannot be accessed

whitcloudfly, 2024-04-29:
可以用STM32cubeide开发hal库的固件，移植难度很小。

ucsoom, 2025-04-03:
My programmer doesn't know why, the Tsop48 chip is connected to the programmer, the programmer can't recognize it, and the Tsop48 chip programmer can recognize it. Can you help me?

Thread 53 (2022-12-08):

Does it support GD32F103VCT6?

myseil, 2022-12-08:
Hi！
I have a GD32F103VCT6 chip, can use it to replace STM32F103VCT6?

myseil, 2022-12-09:
GD32F103VCT6 is determined to be available and can replace STM32F103VCT6

myseil, 2022-12-20:
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
I'm sorry! Using GD32F103VCT6 does not work properly, and the data written is not consistent. I don't know where this is the problem! Attached is the [GD32F103VCT6 datasheet](https://cdn.jsdelivr.net/gh/myseil/PicGoCDN@master/img/GD32F103xxDatasheet_Rev2.12.pdf)

myseil, 2022-12-20:
The main frequency of GD32F103VCT6 is higher than that of STM32F103VCT6, is this the reason?

alexgrach, 2022-12-20:
GD32F303VCT6 is used intead of STM32F103VCT6 in 3d printer boards

myseil, 2022-12-22:
> GD32F303VCT6 is used intead of STM32F103VCT6 in 3d printer boards

？？？

ssp97, 2023-05-16:
https://oshwhub.com/myseil/nandopen
In this article, it is proven that GD32F103 is binary compatible with STM32F103.

myseil, 2023-05-17:
>

This project was created by me and can not be used with GD32!

ssp97, 2023-05-17:
> >
>
> This project was created by me and can not be used with GD32!

Yes. I saw in your article that it was written, "The program can be directly flashed following the original author's steps, just by replacing the STM tools with GD tools, it's quite simple."(程序按照原作者的步骤直接刷，就是STM的工具换成GD的工具，很简单) That's why I believed that running it on GD32 has already been achieved.

myseil, 2023-05-18:
>

emmm！立创的这个项目也是我搬过去的，也是用的GD工具刷的，然后和STM的进行对比验证，会发现数据不一致！

bbogush, 2023-05-23:
GD32 is not supported. Closing issue.

Closed 2023-05-23.

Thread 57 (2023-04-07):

Porting to stm32F407 series?

deividAlfa, 2023-04-07:
These are even cheaper than the stm32f103, while way faster, also cheap development boards can be found everywhere, while the 100pin f103 is not commonly found.
Would it be very hard to add support for it?

Cheers

bbogush, 2023-05-23:
Thanks for idea! Unfortunately effort developing new board and adding support is big. No plans for this now.

Closed 2023-05-23.

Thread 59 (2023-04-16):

Is K9F1G08U0D supported?

hpznot, 2023-04-16:
I added the K9F1G08U0D chip, but there was an warning:"Warning: QXcbConnection: XCB error: 3 (BadWindow), sequence: 14950, resource id: 13199545, major code: 40 (TranslateCoords), minor code: 0". And The following prompt appears when I connect.
"Info: Detecting chip ...
Info: ID 0xcf 0xcf 0xcf 0xcf 0xcf
Info: ID 0x80 0x80 0x80 0x80 0x02
Info: Chip not found in database
Error: Chip size is not set
Error: Chip size is not set
Info: Chip page size is unknown
Info: Reading bad blocks ...
Info: Bad blocks have been successfully read"
The above operations are detected,erased,read,written and read bad blocks in sequence.
[K9F1G08U0D-Samsung.pdf](https://github.com/bbogush/nand_programmer/files/11241958/K9F1G08U0D-Samsung.pdf)

deividAlfa, 2023-04-16:
Check
https://github.com/bbogush/nand_programmer/blob/master/qt/nando_parallel_chip_db.csv

Add a new entry for your chip.

hpznot, 2023-04-16:
> It seems supported: https://github.com/bbogush/nand_programmer/blob/master/qt/nando_parallel_chip_db.csv
>
> However your ids seem strange. Maybe a bad connection?

The chip is soldered. I have also tried changing the chip, but it still doesn't work.

hpznot, 2023-04-19:
I found that I still have the same problem using K91G08U0E. Why is this?

hpznot, 2023-04-19:
Can 1117 output 3.28V be used?

> It seems supported: https://github.com/bbogush/nand_programmer/blob/master/qt/nando_parallel_chip_db.csv
>
> However your ids seem strange. Maybe a bad connection?

Can 1117 output 3.28V be used?

deividAlfa, 2023-04-19:
The list has the K9F2G08U0A& M parts, but not the D, each one has a different ID.
The "D" ID is ```EC F1 00 95 40```

# name	page size	block size	total size	spare size	bad block mark off.	tCS	tCLS	tALS	tCLR	tAR	tWP	tRP	tDS	tCH	tCLH	tALH	tWC	tRC	tREA	row cycles	col. cycles	read 1 cycle com.	read 2 cycle com.	read spare com.	read ID com.	reset com.	write 1 cycle com.	write 2 cycle com.	erase 1 cycle com.	erase 2 cycle com.	status com.	set feat. com.	en. ECC addr	en. ECC val.	dis. ECC val.	ID1	ID2	ID3	ID4	ID5

K9G8G08U0D	2048	262144	1073741824	64	0	20	12	12	10	10	12	12	12	5	5	5	25	25	20	3	2	0	48	-	144	255	128	16	96	208	112	-	-	-	-	236	241	00	149	64

Closed 2023-05-23.

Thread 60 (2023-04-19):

K9K2G08U0M SLC Die Stack series support

loki-amorf, 2023-04-19:
Is any big difference in work logic between K9K2G08U0M and K9F2G08U0B for example?

My quick research third symbol meaning
F : SLC Normal
K : SLC Die Stack
some of SLC Die Stack chips have 2 chip enable pin CE0/CE1 and CE0 but K9K2G08U0M has only one CE

bbogush, 2023-05-23:
No big difference, maybe some timing parameters. K9K2G08U0M is 1.8V which is currently not supported.

Closed 2023-05-23.

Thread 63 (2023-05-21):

Hangs 3.5.0

Sana956, 2023-05-21:
Ver.  3.5.0
Hangs when writing on the second BB.

(Info: "Bad block at 0x0035a840 size 0x00021000"
Info: "Bad block at 0x0035b080 size 0x00021000")
K9F1G8U0E

Doesn't work either - "Read bad blocks":
(Error: "Programmer sent error: (104) Failed to read chip")

Everything else works.
Windows 10 64x

bbogush, 2023-05-21:
Thanks for trying new firmware. I cannot reproduce reported issue on my board. Error 104 is reported when there is hardware communication problem between STM and NAND. Bad block on write also points to this.

v6760hu, 2023-05-23:
可以弄个GD32F103VCT6 的固件吗  STM32F103VCT6  快

Closed 2023-05-23.

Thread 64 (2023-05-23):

可以弄个GD32F103VCT6 的固件吗 STM32F103VCT6 快

v6760hu, 2023-05-23:
主频也比 STM32F103VCT6 高  而且还提升了写入速度

bbogush, 2023-05-23:
Thanks for idea! Looks GD32F103VCT6 is good low price alternative. Unfortunately developing new board and adding support is big effort even if they looks similar. No plans for this now.

v6760hu, 2023-08-05:
stm32f407vet

?凡事↗都飞
***@***.***

&nbsp;

------------------&nbsp;原始邮件&nbsp;------------------
发件人:                                                                                                                        "bbogush/nand_programmer"                                                                                    ***@***.***&gt;;
发送时间:&nbsp;2023年5月24日(星期三) 凌晨4:04
***@***.***&gt;;
***@***.******@***.***&gt;;
主题:&nbsp;Re: [bbogush/nand_programmer] 可以弄个GD32F103VCT6 的固件吗 STM32F103VCT6 快 (Issue #64)

Thanks for idea! Looks GD32F103VCT6 is good low price alternative. Unfortunately developing new board and adding support is big effort even if they looks similar. No plans for this now.

—
Reply to this email directly, view it on GitHub, or unsubscribe.
You are receiving this because you authored the thread.Message ID: ***@***.***&gt;

Closed 2023-05-23.

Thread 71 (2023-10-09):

Issue with EN25F80-75HCP

kooroshi60, 2023-10-09:
I noticed that Nando programmer can't read the device ID of this particular chip. I tested 3 devices with same result. I was wondering if anyone has experienced such an issue?

Jichao, 2023-10-14:
any error message?

kooroshi60, 2023-11-10:
There is no any error messages. Programmer detects a wrong ID and in result the SPI chip is unrecognizable.

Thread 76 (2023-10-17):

准备把nando用STM32CubeMX和STM32CubeIDE移植到STM32F407VET6的HAL库上。bootloader和app的cdc驱动已做好了。有兴趣可以一起加入

whitcloudfly, 2023-10-17:
准备开发带触摸屏的脱机烧写的版本。

whitcloudfly, 2023-10-23:
目前在作者的代码基础上移植了STM32F407VET6的版本。https://github.com/whitcloudfly/CUBE_NANDO_HAL

whitcloudfly, 2023-11-13:
STM32F103VET6和STM32F407VCT6的HAL库版本均已移植完成。但是写入校验奇数块出错。在Nando上测试原版3.5.0代码也是同样问题。

whitcloudfly, 2023-11-15:
问题出在w25q256jv需要启动4字节地址。

whitcloudfly, 2024-05-12:
项目已完成

whitcloudfly, 2025-04-03:
可以

------------------&nbsp;原始邮件&nbsp;------------------
发件人:                                                                                                                        "bbogush/nand_programmer"                                                                                    ***@***.***&gt;;
发送时间:&nbsp;2025年3月31日(星期一) 中午1:52
***@***.***&gt;;
***@***.***&gt;;"State ***@***.***&gt;;
主题:&nbsp;Re: [bbogush/nand_programmer] 准备把nando用STM32CubeMX和STM32CubeIDE移植到STM32F407VET6的HAL库上。bootloader和app的cdc驱动已做好了。有兴趣可以一起加入 (Issue #76)

pcb板是可以用103的吗？

—
Reply to this email directly, view it on GitHub, or unsubscribe.
You are receiving this because you modified the open/close state.Message ID: ***@***.***&gt;
  mhzx left a comment (bbogush/nand_programmer#76)

pcb板是可以用103的吗？

—
Reply to this email directly, view it on GitHub, or unsubscribe.
You are receiving this because you modified the open/close state.Message ID: ***@***.***&gt;

Closed 2024-07-13.

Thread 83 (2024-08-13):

Request of sandisk

DRCRecoveryData, 2024-08-13:
Hi,

Can i dump nand from sandisk sdcard have config?

```
// Chip
Company      Toshiba
Name         BGA-152 05549 064G
ID code      45 3e 99 b3

// Structure
Bus          8
Banks        1 x 64 GB
Page         18336
Block        0xd6e000
Blocks       0x2000

// Read
Cmd          WL
Col          2
Row          3
DDR          false

// Timings
RE_Up        2
RE_Down      2

// Special
Power
Retry        Sandisk v3
Skip_Mask_1  0xffffffff
Skip_Page_1  0xffffffff
Skip_Mask_2  0xffffffff
Skip_Page_2  0xffffffff
Join CE      1-3
```

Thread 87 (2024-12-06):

Need help with Macos port over

liqili, 2024-12-06:
Hi there,

I’m working on building Macos software and I will eventually merge it back.

Currently I made a good progress to build and package the QT application. However I got one issue with the low bandrate(921600) in OSX and writing to the device seems to be hanging after a page was sent. The read device functioned well though.

When I check the source code, I find writing to device is splitting into a few small writing of 64B and block for read ack once a page data is sent. My question is if I try to send 1024B rather than 64B what I need to adjust in the firmware? Just need change 64 to 1024? Or anything else I need pay attention to.

Any help is appreciated!

liqili, 2024-12-14:
Done, please delete it

Closed 2024-12-14.

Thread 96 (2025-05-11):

Yamaha MX100-A Disklavier Issue

kooroshi60, 2025-05-11:
Yamaha MX100-A Disklavier uses a 34 Pin connector. I checked the signal names and they are exactly match with Gotek. On the original disk drive S0 and Motor jumpers are present. Pin2 (Disk change) is also pulled up to +5v via a jumper. I modified my Gotek and connected the pin 36 of STM32 to Pin16 (Motor) of the Gotek port and pulled it up to +5v in order to follow the jumper settings of the original FDD. Despite all I did it doesn't work and Disklavier can't detect it. What could possibly gone wrong? I see that the N-Drive is working on MX100-A. Nalbantov is a Gotek clone am I right?
I appreciate any help or suggestion.

kooroshi60, 2025-05-11:
Sorry! Wrong repository!!

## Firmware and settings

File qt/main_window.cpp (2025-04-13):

/*  Copyright (C) 2020 NANDO authors
 *  This program is free software; you can redistribute it and/or modify
 *  it under the terms of the GNU General Public License version 3.
 */

#include "main_window.h"
#include "ui_main_window.h"
#include "settings_programmer_dialog.h"
#include "parallel_chip_db_dialog.h"
#include "spi_chip_db_dialog.h"
#include "firmware_update_dialog.h"
#include "parallel_chip_db.h"
#include "spi_chip_db.h"
#include "logger.h"
#include "about_dialog.h"
#include "settings.h"
#include <QDebug>
#include <QFileDialog>
#include <QFile>
#include <QSettings>
#include <QStringList>
#include <QMessageBox>
#include <memory>
#include <QTimer>
#include <QTime>

#define HEADER_ADDRESS_WIDTH 80
#define HEADER_HEX_WIDTH 340
#define BUFFER_ROW_HEIGHT 20

#define CHIP_NAME_DEFAULT "NONE"
#define CHIP_INDEX_DEFAULT 0
#define CHIP_INDEX2ID(index) (index - 1)
#define CHIP_ID2INDEX(id) (id + 1)

void MainWindow::initBufTable()
{
#ifdef Q_OS_WIN32
    QFont font("Courier New", 9);
    ui->dataViewer->setFont(font);
#endif
}

void MainWindow::resetBufTable()
{
    ui->dataViewer->setFile(ui->filePathLineEdit->text());
    buffer.buf.clear();
}

MainWindow::MainWindow(QWidget *parent) : QMainWindow(parent),
    ui(new Ui::MainWindow)
{
    Logger *logger = Logger::getInstance();

    ui->setupUi(this);

    logger->setTextEdit(ui->logTextEdit);

    initBufTable();
#ifdef Q_OS_WIN32
    QFont font("Courier New", 9);
    ui->firstSpinBox->setFont(font);
    ui->lastSpinBox->setFont(font);
#endif
    ui->firstSpinBox->setEnabled(false);
    ui->lastSpinBox->setEnabled(false);

    prog = new Programmer(this);
    updateProgSettings();

    updateChipList();

    connect(ui->chipSelectComboBox, SIGNAL(currentIndexChanged(int)),
        this, SLOT(slotSelectChip(int)));

    connect(ui->actionConnect, SIGNAL(triggered()), this,
        SLOT(slotProgConnect()));
    connect(ui->actionReadId, SIGNAL(triggered()), this,
        SLOT(slotProgReadDeviceId()));
    connect(ui->actionErase, SIGNAL(triggered()), this,
        SLOT(slotProgErase()));
    connect(ui->actionRead, SIGNAL(triggered()), this,
        SLOT(slotProgRead()));
    connect(ui->actionVerify, SIGNAL(triggered()), this,
            SLOT(slotProgVerify()));
    connect(ui->actionWrite, SIGNAL(triggered()), this,
        SLOT(slotProgWrite()));
    connect(ui->actionReadBadBlocks, SIGNAL(triggered()), this,
        SLOT(slotProgReadBadBlocks()));
    connect(ui->actionProgrammer, SIGNAL(triggered()), this,
        SLOT(slotSettingsProgrammer()));
    connect(ui->actionParallelChipDb, SIGNAL(triggered()), this,
        SLOT(slotSettingsParallelChipDb()));
    connect(ui->actionSpiChipDb, SIGNAL(triggered()), this,
        SLOT(slotSettingsSpiChipDb()));
    connect(ui->actionAbout, SIGNAL(triggered()), this,
        SLOT(slotAboutDialog()));
    connect(ui->detectPushButton, SIGNAL(clicked()), this,
        SLOT(slotDetectChip()));
    connect(ui->actionFirmwareUpdate, SIGNAL(triggered()), this,
        SLOT(slotFirmwareUpdateDialog()));
    connect(ui->selectFilePushButton, SIGNAL(clicked()), this,
        SLOT(slotSelectFilePath()));
    connect(ui->filePathLineEdit, SIGNAL(editingFinished()), this,
        SLOT(slotFilePathEditingFinished()));

    ui->filePathLineEdit->setText(QDir::tempPath() + "/nando_tmp.bin");
    QSettings settings(SETTINGS_ORGANIZATION_NAME, SETTINGS_APPLICATION_NAME);
    ui->filePathLineEdit->setText(settings.value(SETTINGS_WORK_FILE_PATH,
        ui->filePathLineEdit->text()).toString());
    ui->dataViewer->setFile(ui->filePathLineEdit->text());
}

MainWindow::~MainWindow()
{
    Logger::putInstance();
    delete ui;
}

void MainWindow::setUiStateConnected(bool isConnected)
{
    ui->chipSelectComboBox->setEnabled(isConnected);
    ui->detectPushButton->setEnabled(isConnected);
    ui->actionFirmwareUpdate->setEnabled(isConnected);
    if (!isConnected)
        ui->chipSelectComboBox->setCurrentIndex(CHIP_INDEX_DEFAULT);
}

void MainWindow::setUiStateSelected(bool isSelected)
{
    ui->actionReadId->setEnabled(isSelected);
    ui->actionErase->setEnabled(isSelected);
    ui->actionRead->setEnabled(isSelected);
    ui->actionWrite->setEnabled(isSelected);
    ui->actionVerify->setEnabled(isSelected);
    ui->actionReadBadBlocks->setEnabled(isSelected);

    ui->firstSpinBox->setEnabled(isSelected);
    ui->lastSpinBox->setEnabled(isSelected);
    if (isSelected)
    {
        QString chipName = ui->chipSelectComboBox->currentText();
        quint32 blocksCount = currentChipDb->blockCountGetByName(chipName);
        ui->firstSpinBox->setMaximum(blocksCount - 1);
        ui->firstSpinBox->setValue(0);
        ui->lastSpinBox->setMaximum(blocksCount - 1);
        ui->lastSpinBox->setValue(blocksCount - 1);
        quint64 chipSize = prog->isIncSpare() ?
            currentChipDb->extendedTotalSizeGetByName(chipName) :
            currentChipDb->totalSizeGetByName(chipName);
        ui->blockSizeValueLabel->setText(QString("0x%1").arg(chipSize / blocksCount, 8, 16, QLatin1Char( '0' )));
    }
}

void MainWindow::slotProgConnectCompleted(quint64 status)
{
    disconnect(prog, SIGNAL(connectCompleted(quint64)), this,
        SLOT(slotProgConnectCompleted(quint64)));

    if (status == UINT64_MAX)
        return;

    qInfo() << "Connected to programmer";
    setUiStateConnected(true);
    ui->actionConnect->setText(tr("Disconnect"));
}

void MainWindow::slotProgConnect()
{
    if (!prog->isConnected())
    {
        if (!prog->connect())
        {
            connect(prog, SIGNAL(connectCompleted(quint64)), this,
                SLOT(slotProgConnectCompleted(quint64)));
        }
    }
    else
    {
        prog->disconnect();
        setUiStateConnected(false);
        ui->actionConnect->setText(tr("Connect"));
        qInfo() << "Disconnected from programmer";
    }
}

void MainWindow::slotProgReadDeviceIdCompleted(quint64 status)
{
    QString idStr;

    disconnect(prog, SIGNAL(readChipIdCompleted(quint64)), this,
        SLOT(slotProgReadDeviceIdCompleted(quint64)));

    if (status == UINT64_MAX)
        return;

    idStr = tr("0x%1 0x%2 0x%3 0x%4 0x%5")
        .arg(chipId.makerId, 2, 16, QLatin1Char('0'))
        .arg(chipId.deviceId, 2, 16, QLatin1Char('0'))
        .arg(chipId.thirdId, 2, 16, QLatin1Char('0'))
        .arg(chipId.fourthId, 2, 16, QLatin1Char('0'))
        .arg(chipId.fifthId, 2, 16, QLatin1Char('0'));
    ui->deviceValueLabel->setText(idStr);

    qInfo() << QString("ID ").append(idStr).toLatin1().data();
}

void MainWindow::slotProgReadDeviceId()
{
    qInfo() << "Reading chip ID ...";
    connect(prog, SIGNAL(readChipIdCompleted(quint64)), this,
        SLOT(slotProgReadDeviceIdCompleted(quint64)));
    prog->readChipId(&chipId);
}

void MainWindow::slotProgEraseCompleted(quint64 status)
{
    disconnect(prog, SIGNAL(eraseChipProgress(quint64)), this,
        SLOT(slotProgEraseProgress(quint64)));
    disconnect(prog, SIGNAL(eraseChipCompleted(quint64)), this,
        SLOT(slotProgEraseCompleted(quint64)));

    if (!status)
        qInfo() << "Chip has been erased successfully";

    setProgress(100);
}

void MainWindow::slotProgEraseProgress(quint64 progress)
{
    uint32_t progressPercent;

    progressPercent = progress * 100ULL / areaSize;
    setProgress(progressPercent);
}

void MainWindow::slotProgErase()
{
    // Add confirmation dialog
    QMessageBox msgBox;
    msgBox.setWindowTitle(tr("Confirm erase"));
    msgBox.setText(tr("Are you sure you want to erase the chip?"));
    msgBox.setIcon(QMessageBox::Warning);
    msgBox.setStandardButtons(QMessageBox::Ok | QMessageBox::Cancel);
    msgBox.setDefaultButton(QMessageBox::Cancel);

    // If the user clicks cancel, exit the function.
    if (msgBox.exec() != QMessageBox::Ok)
    {
        qInfo() << "User canceled the erase operation";
        return;
    }

 
    quint64 start_address =
        ui->blockSizeValueLabel->text().toULongLong(nullptr, 16)
        * ui->firstSpinBox->value();
    areaSize =
        ui->blockSizeValueLabel->text().toULongLong(nullptr, 16)
            * (ui->lastSpinBox->value() + 1) - start_address;

    if (!areaSize)
    {
        qCritical() << "Chip size not set";
        return;
    }

    qInfo() << "Erasing chip ...";

    setProgress(0);

    connect(prog, SIGNAL(eraseChipCompleted(quint64)), this,
        SLOT(slotProgEraseCompleted(quint64)));
    connect(prog, SIGNAL(eraseChipProgress(quint64)), this,
        SLOT(slotProgEraseProgress(quint64)));

    prog->eraseChip(start_address, areaSize);
}

void MainWindow::slotProgReadCompleted(quint64 readBytes)
{
    disconnect(prog, SIGNAL(readChipProgress(quint64)), this,
        SLOT(slotProgReadProgress(quint64)));
    disconnect(prog, SIGNAL(readChipCompleted(quint64)), this,
        SLOT(slotProgReadCompleted(quint64)));

    ui->filePathLineEdit->setDisabled(false);
    ui->selectFilePushButton->setDisabled(false);

    setProgress(100);

    if (readBytes == UINT64_MAX)
    {
        workFile.close();
        return;
    }

    buffer.mutex.lock();
    workFile.write((const char *)buffer.buf.data(), buffer.buf.size());
    buffer.buf.clear();
    buffer.mutex.unlock();

    if (readBytes != (quint64)workFile.size())
    {
        qCritical() << "Read operation returned more or less than requested: " <<
            readBytes << "!=" << workFile.size();
        workFile.resize(0);
    }

    workFile.close();
    qInfo() << "Data has been successfully read";
    ui->dataViewer->setFile(ui->filePathLineEdit->text());
}

void MainWindow::slotProgReadProgress(quint64 progress)
{
    uint32_t progressPercent;

    progressPercent = progress * 100ULL / areaSize;
    setProgress(progressPercent);

    buffer.mutex.lock();
    workFile.write((const char *)buffer.buf.data(), buffer.buf.size());
    buffer.buf.clear();
    buffer.mutex.unlock();
}

void MainWindow::slotProgRead()
{
    quint64 start_address =
            ui->blockSizeValueLabel->text().toULongLong(nullptr, 16)
            * ui->firstSpinBox->value();
    areaSize  =
            ui->blockSizeValueLabel->text().toULongLong(nullptr, 16)
            * (ui->lastSpinBox->value() + 1) - start_address;

    if (!areaSize)
    {
        qCritical() << "Chip size is not set";
        return;
    }

    workFile.setFileName(ui->filePathLineEdit->text());
    if (workFile.exists())
    {
        QMessageBox msgBox;
        msgBox.setIcon(QMessageBox::Warning);
        msgBox.setText("Replace data in current file?");
        msgBox.setInformativeText("Selected file name is exist.");
        msgBox.setStandardButtons(QMessageBox::Ok | QMessageBox::Cancel);
        msgBox.setDefaultButton(QMessageBox::Cancel);
        if (msgBox.exec() == QMessageBox::Cancel)
        {
            workFile.close();
            return;
        }
    }

    if (!workFile.open(QIODevice::WriteOnly))
    {
        qCritical() << "Failed to open file:" << ui->filePathLineEdit->text()
            << ", error:" << workFile.errorString();
        return;
    }

    workFile.resize(0);
    resetBufTable();
    buffer.buf.clear();

    qInfo() << "Reading data ...";
    setProgress(0);

    connect(prog, SIGNAL(readChipCompleted(quint64)), this,
        SLOT(slotProgReadCompleted(quint64)));
    connect(prog, SIGNAL(readChipProgress(quint64)), this,
        SLOT(slotProgReadProgress(quint64)));

    ui->filePathLineEdit->setDisabled(true);
    ui->selectFilePushButton->setDisabled(true);

    prog->readChip(&buffer, start_address, areaSize, true);
}

void MainWindow::slotProgVerifyCompleted(quint64 readBytes)
{
    disconnect(prog, SIGNAL(readChipProgress(quint64)), this,
               SLOT(slotProgVerifyProgress(quint64)));
    disconnect(prog, SIGNAL(readChipCompleted(quint64)), this,
               SLOT(slotProgVerifyCompleted(quint64)));

    ui->filePathLineEdit->setDisabled(false);
    ui->selectFilePushButton->setDisabled(false);

    setProgress(100);
    workFile.close();
    buffer.buf.clear();

    qInfo() << readBytes << " bytes read. Verify end."  ;
}

void MainWindow::slotProgVerifyProgress(quint64 progress)
{
    uint32_t progressPercent;

    progressPercent = progress * 100ULL / areaSize;
    setProgress(progressPercent);

    QVector<uint8_t> cmpBuffer;
    buffer.mutex.lock();
    cmpBuffer.resize(buffer.buf.size());

    qint64 readSize = workFile.read((char *)cmpBuffer.data(), buffer.buf.size());

    if (readSize < 0)
    {
        qCritical() << "Failed to read file";
    }
    else if (readSize == 0)
    {
        qCritical() << "File read 0 byte";
    }

    for(uint32_t i = 0; i < readSize; i++)
    {
        if(cmpBuffer.at(i) != buffer.buf.at(i))
        {
            uint64_t block = progress / ui->blockSizeValueLabel->text().toULongLong(nullptr, 16)
                             + ui->firstSpinBox->text().toULongLong(nullptr, 10) - 1;
            uint64_t byte = progress - ui->blockSizeValueLabel->text().toULongLong(nullptr, 16)
                            + ui->firstSpinBox->text().toULongLong(nullptr, 10)
                            * ui->blockSizeValueLabel->text().toULongLong(nullptr, 16) + i;
            qCritical() << "Wrong block: " << QString("%1").arg(block)
                << ", Wrong byte addr: "
                << QString("0x%1").arg(byte, 8, 16, QLatin1Char( '0' ));
            break;
        }
    }

    buffer.buf.clear();
    buffer.mutex.unlock();
}

void MainWindow::slotProgVerify()
{
    int index;
    QString chipName;

    workFile.setFileName(ui->filePathLineEdit->text());
    if (!workFile.open(QIODevice::ReadOnly))
    {
        qCritical() << "Failed to open compare file:" << ui->filePathLineEdit->text() << ", error:" <<
            workFile.errorString();
        return;
    }
    if (!workFile.size())
    {
        qInfo() << "Compare file is empty";
        return;
    }

    index = ui->chipSelectComboBox->currentIndex();
    if (index <= CHIP_INDEX_DEFAULT)
    {
        qInfo() << "Chip is not selected";
        return;
    }

    chipName = ui->chipSelectComboBox->currentText();
    pageSize = prog->isIncSpare() ?
                   currentChipDb->extendedPageSizeGetByName(chipName) :
                   currentChipDb->pageSizeGetByName(chipName);
    if (!pageSize)
    {
        qInfo() << "Chip page size is unknown";
        return;
    }

    quint64 start_address =
        ui->blockSizeValueLabel->text().toULongLong(nullptr, 16)
        * ui->firstSpinBox->value();

    areaSize = workFile.size();

    if (areaSize % pageSize)
    {
        areaSize = (areaSize / pageSize + 1) * pageSize;
    }

    quint64 setSize =
        ui->blockSizeValueLabel->text().toULongLong(nullptr, 16)
            * (ui->lastSpinBox->value() + 1) - start_address;

    if (setSize < areaSize)
        areaSize = setSize;

    qInfo() << "Reading data ...";
    setProgress(0);

    connect(prog, SIGNAL(readChipCompleted(quint64)), this,
            SLOT(slotProgVerifyCompleted(quint64)));
    connect(prog, SIGNAL(readChipProgress(quint64)), this,
            SLOT(slotProgVerifyProgress(quint64)));

    ui->filePathLineEdit->setDisabled(true);
    ui->selectFilePushButton->setDisabled(true);

    buffer.buf.clear();

    prog->readChip(&buffer, start_address, areaSize, true);
}

void MainWindow::slotProgWriteCompleted(int status)
{
    disconnect(prog, SIGNAL(writeChipProgress(quint64)), this,
        SLOT(slotProgWriteProgress(quint64)));
    disconnect(prog, SIGNAL(writeChipCompleted(int)), this,
        SLOT(slotProgWriteCompleted(int)));

    ui->filePathLineEdit->setDisabled(false);
    ui->selectFilePushButton->setDisabled(false);

    if (!status)
        qInfo() << "Data has been successfully written";

    setProgress(100);
    workFile.close();
}

void MainWindow::slotProgWriteProgress(quint64 progress)
{
    uint32_t progressPercent;

    progressPercent = progress * 100ULL / areaSize;
    setProgress(progressPercent);

    std::unique_lock<std::mutex> lck(buffer.mutex);

    qint64 readSize = workFile.read((char *)buffer.buf.data(), pageSize);
    if (readSize < 0)
    {
        qCritical() << "Failed to read file";
        return;
    }
    else if (readSize == 0)
    {
        return;
    }
    else if (readSize < pageSize)
    {
        std::fill(buffer.buf.begin() + readSize, buffer.buf.end(), 0xFF);
    }

    // Notify writer that new data is ready
    buffer.ready = true;
    buffer.cv.notify_one();
}

void MainWindow::slotProgWrite()
{
    int index;
    QString chipName;

    workFile.setFileName(ui->filePathLineEdit->text());
    if (!workFile.open(QIODevice::ReadOnly))
    {
        qCritical() << "Failed to open file:" << ui->filePathLineEdit->text() << ", error:" <<
            workFile.errorString();
        return;
    }
    if (!workFile.size())
    {
        qInfo() << "Write file is empty";
        return;
    }

    index = ui->chipSelectComboBox->currentIndex();
    if (index <= CHIP_INDEX_DEFAULT)
    {
        qInfo() << "Chip is not selected";
        return;
    }

    chipName = ui->chipSelectComboBox->currentText();
    pageSize = prog->isIncSpare() ?
        currentChipDb->extendedPageSizeGetByName(chipName) :
        currentChipDb->pageSizeGetByName(chipName);
    if (!pageSize)
    {
        qInfo() << "Chip page size is unknown";
        return;
    }

    quint64 start_address =
            ui->blockSizeValueLabel->text().toULongLong(nullptr, 16)
            * ui->firstSpinBox->value();

    areaSize = workFile.size();

    if (areaSize % pageSize)
    {
        areaSize = (areaSize / pageSize + 1) * pageSize;
    }

    quint64 setSize =
            ui->blockSizeValueLabel->text().toULongLong(nullptr, 16)
            * (ui->lastSpinBox->value() + 1) - start_address;

    if (setSize < areaSize)
        areaSize = setSize;

    qInfo() << "Writing data ...";

    connect(prog, SIGNAL(writeChipCompleted(int)), this,
        SLOT(slotProgWriteCompleted(int)));
    connect(prog, SIGNAL(writeChipProgress(quint64)), this,
        SLOT(slotProgWriteProgress(quint64)));

    ui->filePathLineEdit->setDisabled(true);
    ui->selectFilePushButton->setDisabled(true);

    buffer.buf.reserve(pageSize);
    buffer.buf.resize(pageSize);
    qint64 readSize = workFile.read((char *)buffer.buf.data(), (qint64)pageSize);
    if (readSize < 0)
    {
        qCritical() << "Failed to read file";
        return;
    }
    else if (readSize == 0)
    {
        qInfo() << "File is empty";
        return;
    }
    else if (readSize < pageSize)
    {
        std::fill(buffer.buf.begin() + readSize, buffer.buf.end(), 0xFF);
    }

    buffer.ready = true;
    prog->writeChip(&buffer, start_address, areaSize, pageSize);
}

void MainWindow::slotProgReadBadBlocksCompleted(quint64 status)
{
    disconnect(prog, SIGNAL(readChipBadBlocksCompleted(quint64)), this,
        SLOT(slotProgReadBadBlocksCompleted(quint64)));
    disconnect(prog, SIGNAL(readChipBadBlocksProgress(quint64)), this,
        SLOT(slotProgReadBadBlocksProgress(quint64)));

    if (!status)
        qInfo() << "Bad blocks have been successfully read";

    setProgress(100);
}

void MainWindow::slotProgReadBadBlocksProgress(quint64 progress)
{
    uint32_t progressPercent;
    QString chipName = ui->chipSelectComboBox->currentText();
    quint64 pageNum =
        currentChipDb->extendedTotalSizeGetByName(chipName) /
        currentChipDb->extendedPageSizeGetByName(chipName);

    progressPercent = progress * 100ULL / pageNum;
    setProgress(progressPercent);
}

void MainWindow::slotProgReadBadBlocks()
{
    qInfo() << "Reading bad blocks ...";

    connect(prog, SIGNAL(readChipBadBlocksCompleted(quint64)), this,
        SLOT(slotProgReadBadBlocksCompleted(quint64)));
    connect(prog, SIGNAL(readChipBadBlocksProgress(quint64)), this,
        SLOT(slotProgReadBadBlocksProgress(quint64)));

    prog->readChipBadBlocks();
}

void MainWindow::slotProgSelectCompleted(quint64 status)
{
    disconnect(prog, SIGNAL(confChipCompleted(quint64)), this,
        SLOT(slotProgSelectCompleted(quint64)));

    if (!status)
    {
        setUiStateSelected(true);
        qInfo() << "Programmer configured successfully";
    }
    else
        setUiStateSelected(false);
}

void MainWindow::slotSelectChip(int selectedChipNum)
{
    QString name;
    ChipInfo *chipInfo;

    if (selectedChipNum <= CHIP_INDEX_DEFAULT)
    {
        setUiStateSelected(false);
        return;
    }

    name = ui->chipSelectComboBox->currentText();
    if (name.isEmpty())
    {
        qCritical() << "Failed to get chip name";
        return;
    }

    if ((chipInfo = parallelChipDb.chipInfoGetByName(name)))
        currentChipDb = &parallelChipDb;
    else if ((chipInfo = spiChipDb.chipInfoGetByName(name)))
        currentChipDb = &spiChipDb;
    else
    {
        qCritical() << "Failed to find chip in DB";
        return;
    }

    qInfo() << "Configuring programmer ...";

    connect(prog, SIGNAL(confChipCompleted(quint64)), this,
        SLOT(slotProgSelectCompleted(quint64)));

    if (chipInfo)
        prog->confChip(chipInfo);
}

void MainWindow::detectChipDelayed()
{

    if (currentChipDb == &spiChipDb)
        qInfo() << "Chip not found in database";
    else
    {
        // Search in next DB
        detectChip(&spiChipDb);
    }
}

void MainWindow::setChipNameDelayed()
{
    QString chipName = currentChipDb->getNameByChipId(chipId.makerId,
        chipId.deviceId, chipId.thirdId, chipId.fourthId, chipId.fifthId);

    for (int i = 0; i < ui->chipSelectComboBox->count(); i++)
    {
        if (!ui->chipSelectComboBox->itemText(i).compare(chipName))
            ui->chipSelectComboBox->setCurrentIndex(i);
    }
}
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

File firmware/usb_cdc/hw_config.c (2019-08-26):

/**
  ******************************************************************************
  * @file    hw_config.c
  * @author  MCD Application Team
  * @version V4.0.0
  * @date    21-January-2013
  * @brief   Hardware Configuration & Setup
  ******************************************************************************
  * @attention
  *
  * <h2><center>&copy; COPYRIGHT 2013 STMicroelectronics</center></h2>
  *
  * Licensed under MCD-ST Liberty SW License Agreement V2, (the "License");
  * You may not use this file except in compliance with the License.
  * You may obtain a copy of the License at:
  *
  *        http://www.st.com/software_license_agreement_liberty_v2
  *
  * Unless required by applicable law or agreed to in writing, software 
  * distributed under the License is distributed on an "AS IS" BASIS, 
  * WITHOUT WARRANTIES OR CONDITIONS OF ANY KIND, either express or implied.
  * See the License for the specific language governing permissions and
  * limitations under the License.
  *
  ******************************************************************************
  */

/* Includes ------------------------------------------------------------------*/

#include "stm32_it.h"
#include "usb_lib.h"
#include "usb_prop.h"
#include "usb_desc.h"
#include "hw_config.h"
#include "usb_pwr.h"

/* Private typedef -----------------------------------------------------------*/
/* Private define ------------------------------------------------------------*/
/* Private macro -------------------------------------------------------------*/
/* Private variables ---------------------------------------------------------*/
ErrorStatus HSEStartUpStatus;
EXTI_InitTypeDef EXTI_InitStructure;
__IO uint32_t packet_sent = 1;
extern __IO uint8_t Send_Buffer[VIRTUAL_COM_PORT_DATA_SIZE] ;
__IO uint32_t packet_receive = 1;
extern __IO uint8_t Receive_length;

uint32_t Send_length;
static void IntToUnicode (uint32_t value , uint8_t *pbuf , uint8_t len);
/* Extern variables ----------------------------------------------------------*/

extern LINE_CODING linecoding;

/* Private function prototypes -----------------------------------------------*/
/* Private functions ---------------------------------------------------------*/
/*******************************************************************************
* Function Name  : Set_System
* Description    : Configures Main system clocks & power
* Input          : None.
* Return         : None.
*******************************************************************************/
void Set_System(void)
{
#if !defined(STM32L1XX_MD) && !defined(STM32L1XX_HD) && !defined(STM32L1XX_MD_PLUS)
  GPIO_InitTypeDef GPIO_InitStructure;
#endif /* STM32L1XX_MD && STM32L1XX_XD */  

#if defined(USB_USE_EXTERNAL_PULLUP)
  GPIO_InitTypeDef  GPIO_InitStructure;
#endif /* USB_USE_EXTERNAL_PULLUP */ 
  
  /*!< At this stage the microcontroller clock setting is already configured, 
       this is done through SystemInit() function which is called from startup
       file (startup_stm32f10x_xx.s) before to branch to application main.
       To reconfigure the default setting of SystemInit() function, refer to
       system_stm32f10x.c file
     */   
#if defined(STM32L1XX_MD) || defined(STM32L1XX_HD)|| defined(STM32L1XX_MD_PLUS) || defined(STM32F37X) || defined(STM32F30X)
  /* Enable the SYSCFG module clock */
  RCC_APB2PeriphClockCmd(RCC_APB2Periph_SYSCFG, ENABLE);
#endif /* STM32L1XX_XD */ 
   
#if !defined(STM32L1XX_MD) && !defined(STM32L1XX_HD) && !defined(STM32L1XX_MD_PLUS) && !defined(STM32F37X) && !defined(STM32F30X)
#ifdef USB_DISCONNECT_GPIO
/* Enable USB_DISCONNECT GPIO clock */
  RCC_APB2PeriphClockCmd(RCC_APB2Periph_GPIO_DISCONNECT, ENABLE);

  /* Configure USB pull-up pin */
  GPIO_InitStructure.GPIO_Pin = USB_DISCONNECT_PIN;
  GPIO_InitStructure.GPIO_Speed = GPIO_Speed_50MHz;
  GPIO_InitStructure.GPIO_Mode = GPIO_Mode_Out_OD;
  GPIO_Init(USB_DISCONNECT, &GPIO_InitStructure);
#endif
#endif /* STM32L1XX_MD && STM32L1XX_XD */
   
#if defined(USB_USE_EXTERNAL_PULLUP)
  /* Enable the USB disconnect GPIO clock */
  RCC_AHBPeriphClockCmd(RCC_AHBPeriph_GPIO_DISCONNECT, ENABLE);

  /* USB_DISCONNECT used as USB pull-up */
  GPIO_InitStructure.GPIO_Pin = USB_DISCONNECT_PIN;
  GPIO_InitStructure.GPIO_Mode = GPIO_Mode_OUT;
  GPIO_InitStructure.GPIO_Speed = GPIO_Speed_2MHz;
  GPIO_InitStructure.GPIO_OType = GPIO_OType_PP;
  GPIO_InitStructure.GPIO_PuPd = GPIO_PuPd_NOPULL;
  GPIO_Init(USB_DISCONNECT, &GPIO_InitStructure);  
#endif /* USB_USE_EXTERNAL_PULLUP */
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

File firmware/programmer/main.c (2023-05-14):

/*  Copyright (C) 2020 NANDO authors
 *  This program is free software; you can redistribute it and/or modify
 *  it under the terms of the GNU General Public License version 3.
 */

#include "nand_programmer.h"
#include "usb.h"
#include "cdc.h"
#include "led.h"
#include "uart.h"
#include "jtag.h"
#include "version.h"
#include "clock.h"
#include <stdio.h>

int main()
{
    uart_init();
    printf("\r\nNAND programmer ver: %d.%d.%d\r\n", SW_VERSION_MAJOR,
        SW_VERSION_MINOR, SW_VERSION_BUILD);

    if (!is_external_clock_avail())
        printf("External clock not detected. Fallback to internal clock.\r\n");

    printf("JTAG init...");
    jtag_init();
    printf("done.\r\n");

    printf("LED init...");
    led_init();
    printf("done.\r\n");

    printf("USB init...");
    usb_init();
    printf("done.\r\n");

    printf("CDC init...");
    cdc_init();
    printf("done.\r\n");

    printf("Programmer init...");
    np_init();
    printf("done.\r\n");

    while (1)
        np_handler();

    return 0;
}

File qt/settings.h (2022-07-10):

/*  Copyright (C) 2020 NANDO authors
 *  This program is free software; you can redistribute it and/or modify
 *  it under the terms of the GNU General Public License version 3.
 */

#ifndef SETTINGS_H
#define SETTINGS_H

#define SETTINGS_ORGANIZATION_NAME "NANDO"
#define SETTINGS_APPLICATION_NAME "NANDO"

#define SETTINGS_PROGRAMMER_SECTION "programmer/"
#define SETTINGS_GUI_SECTION "GUI/"
#define SETTINGS_USB_DEV_NAME SETTINGS_PROGRAMMER_SECTION "usb_dev_name"
#define SETTINGS_SKIP_BAD_BLOCKS SETTINGS_PROGRAMMER_SECTION "skip_bad_blocks"
#define SETTINGS_INCLUDE_SPARE_AREA SETTINGS_PROGRAMMER_SECTION \
    "include_spare_area"
#define SETTINGS_ENABLE_HW_ECC SETTINGS_PROGRAMMER_SECTION \
    "enable_hw_ecc"
#define SETTINGS_ENABLE_ALERT SETTINGS_GUI_SECTION "enable_alert"
#define SETTINGS_WORK_FILE_PATH SETTINGS_GUI_SECTION "work_file_path"

#endif // SETTINGS_H

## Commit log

2017-02-04 Made schematic and pcb
    [nand_programmator.kicad_pcb, nand_programmator.sch]
2017-02-05 PCB: added plated areas and generated gerber files
    [nand_programmator.kicad_pcb]
2017-02-05 Fixed value if R9 resistor and added JTAG label
    [nand_programmator.kicad_pcb, nand_programmator.sch]
2017-02-05 Added title and version of documents
    [nand_programmator.kicad_pcb, nand_programmator.sch]
2017-02-26 Fixed overlapping wires
    [nand_programmator.kicad_pcb]
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2017-04-01 qt: print wrong response code
2017-04-02 qt: replaced chip info lookup by id to lookup by name
    [main_window.cpp]
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2017-04-02 Fixed page read loop
    [main.c]
2017-04-09 Fixed uninitiazed read address
    [main.c]
2017-04-30 qt: Implemented logger class to redirect error and info messages to program log widget
    [main_window.cpp]
2017-05-05 qt: replaced regular buffer table to model-view
    [main_window.cpp]
2017-07-30 Return status immidiatelly when NAND operation error occur
    [fsmc_nand.c]
2018-03-04 Revert of 889053d484c064866f5ed6dea0591c61913cf853 (Implemented support of double buffer for CDC read and write) due to regression
    [hw_config.c]
2018-03-09 Fixed sending of 64 sized packets via USB
    [hw_config.c]
2018-03-09 qt: Error in serial writer is unknown on timeout thereby don't print it
2018-04-22 Added debug and error messages
    [main.c]
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2018-05-20 Fixed DEBUG define compilation
    [main.c]
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2018-09-23 qt: Added USB device name to error message
2018-09-30 qt: fixed adding of log message in current cursor position
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2018-10-01 Implemented send of error codes in error message
    [main.c]
2018-10-01 Fixed address invalid error when whole flash is written
    [main.c]
2018-10-31 kicad: use local libraries
    [nand_programmator.kicad_pcb, nand_programmator.sch]
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2018-11-11 kicad: update project to 5.0.1
    [nand_programmator.kicad_pcb, nand_programmator.sch]
2018-11-18 kicad: added boot switches
    [nand_programmator.kicad_pcb, nand_programmator.sch]
2018-11-18 kicad: added BOM file
    [nand_programmator.csv]
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2018-11-25 Fixed write of unaligned to page size file
    [main.c]
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2018-12-05 kicad: moved BOM out of project
    [nand_programmator.csv]
2018-12-07 kicad: reduced size of board; JTAG replaced by SWD; Added serial; Replaced quartz footprint to SMD; Added RD & WR LEDs;
    [nand_programmator.kicad_pcb, nand_programmator.sch]
2018-12-09 kicad: moved crystal and pin header footprints to local library
    [nand_programmator.kicad_pcb, nand_programmator.sch]
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2018-12-24 fw: removed wrong debug
    [main.c]
2018-12-25 fw: CDC calls replaced by callbacks
    [main.c]
2018-12-25 fw: send error/status inplace
    [main.c]
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2018-12-29 Return -1 on error explicitly
    [nand_programmer.c]
2018-12-30 Return error when read address/length is unaligned
    [nand_programmer.c]
2018-12-30 Return error when write address/length is unaligned
    [nand_programmer.c]
2018-12-30 Fixed address exceeded error on read
    [nand_programmer.c]
2018-12-30 Fixed send of error code
    [nand_programmer.c]
2018-12-30 Added address/length exceeded errors for write command
    [nand_programmer.c]
2018-12-30 Skip bad blocks on erase
    [nand_programmer.c]
2018-12-31 Added UI configuration for skipping bad blocks
    [main_window.cpp, nand_programmer.c]
2019-01-01 Implemented skip bad block functionality for read operation
    [main_window.cpp, nand_programmer.c]
2019-02-26 Skip bad blocks on write
    [nand_programmer.c]
2019-02-26 Fixed write LED state on error
    [nand_programmer.c]
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2019-03-03 Read bad blocks automatically if skip flag is set
    [nand_programmer.c]
2019-03-03 Implemented skipped bad block status message
    [nand_programmer.c]
2019-03-17 Chip DB moved to external CSV file
    [nando_chip_db.csv]
2019-04-10 Implemented add/delete of chips from UI
    [nando_chip_db.csv]
2019-04-10 Fixed free of read buffer
    [main_window.cpp]
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2019-04-27 Fixed wrong slot for read ID in disconnect
    [main_window.cpp]
2019-04-28 Fixed compilation error on bad block debug print
    [nand_programmer.c]
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2019-05-05 Fixed error code for non-aligned length
    [nand_programmer.c]
2019-05-05 Fix duplicated entries in bad block table
    [nand_programmer.c]
2019-06-02 Added K9F1G08U0E to the chip database
    [nando_chip_db.csv]
2019-06-02 Revert "Increased TSOP-48 socket holes to facilicate mounting"
    This reverts commit 0c7ae75244ce43bebd9ec9334b9dce20034cc5b3.
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2019-06-09 Main PCB and socket PCB separated to allow usage of different adapters
    [adapter_tsop48.kicad_pcb, adapter_tsop48.sch, nand_programmator.kicad_pcb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]
2019-06-12 Add TSOP-48 adapter for soldering
    [adapter_tsop48_solder.kicad_pcb, adapter_tsop48_solder.sch]
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2019-06-12 Updated schematic and PCB versions
    [nand_programmator.kicad_pcb, nand_programmator.sch]
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2019-06-12 Settings for gerber files
    [adapter_tsop48.kicad_pcb, adapter_tsop48_solder.kicad_pcb]
2019-08-26 Fallback to internal clock if problem with external clock present. The MCU clock in this case is 48MHz instead of 72MHz
    [hw_config.c, main.c]
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2019-08-28 Added spare area size parameter
    [nando_chip_db.csv]
2019-09-15 Implemented configuration of row and column cycles required for addresing read/write/erase operation
    [nando_chip_db.csv]
2019-09-15 Fixed name convension in chip DB file
    [nando_chip_db.csv]
2019-09-15 Refactore header name convension in chip DB file
    [nando_chip_db.csv]
2019-09-22 Implemented configuration of NAND commands
    [nando_chip_db.csv]
2019-09-24 Implemented configuration of bad block mark offset
    [nando_chip_db.csv]
2019-09-24 Added support of HY27US08561A
    [nando_chip_db.csv]
2019-09-28 Mark optional commands by '-' symbol
    [nando_chip_db.csv]
2019-10-06 Added BOOT0 to PCB to allow full erase using buildin bootloader
    [nand_programmator.kicad_pcb, nand_programmator.sch]
2019-10-13 Use dedicated command to read spare area
    [nando_chip_db.csv]
2019-10-19 Added TC58NVG2S3E to chip database
    [nando_chip_db.csv]
2020-01-12 Added chip ID to DB
    [nando_chip_db.csv]
2020-01-18 Fixed ID of K9F2G08U0C
    [nando_chip_db.csv]
2020-02-18 When initializing nand block table use sizeof to set right size for memset.
    Since memset works byte by byte and the following table is uint32_t type, essentially memset here sets only 20/4=5 first bytes of table and I don't think that it's intended.
    Also, gcc9 is complaining about this aswell:
    nand_bad_block.c: In function 'nand_bad_block_table_init':
    nand_bad_block.c:16:5: error: 'memset' used with length equal to number of elements without multiplication by element size [-Werror=memset-elt-size]
    16 | memset(nand_bad_block_table, 0, NAND_BAD_BLOCK_TABLE_SIZE);
    | ^~~~~~
    with the exact gcc version:
    # arm-none-eabi-gcc --version
    arm-none-eabi-gcc (Arch Repository) 9.2.0
    Cop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
2020-03-08 Removed redundant column in chip DB header
    [nando_chip_db.csv]
2020-03-15 Added support of K9F1208U0B
    [nando_chip_db.csv]
2020-03-15 Added support of F59L2G81A
    [nando_chip_db.csv]
2020-03-15 Fix bad block table overflow: read whole page in order to access spare area
    [nand_programmer.c]
2020-04-18 Upgrade: don't change active image until reset
    [main.c, nand_programmer.c]
2020-05-26 Single side components pcb
    [nand_programmator.kicad_pcb, nand_programmator.sch]
2020-05-28 Replaced quartz by HC49 package, rerouted most of the board
    [nand_programmator.kicad_pcb, nand_programmator.sch]
2020-05-28 Updated PCB text : NANDO v3.2
    [nand_programmator.kicad_pcb, nand_programmator.sch]
2020-06-07 Added Farnell refs, fixed leds order
    [nand_programmator.kicad_pcb, nand_programmator.sch]
2020-06-07 Actually fill ground planes
    [nand_programmator.kicad_pcb]
2020-06-09 Swapped PWR led direction to march other leds
    [nand_programmator.kicad_pcb]
2020-06-14 Swapped R1 and R15 values
    [nand_programmator.kicad_pcb, nand_programmator.sch]
2020-06-18 Had swapped rd and wr leds. Now corrected
    [nand_programmator.kicad_pcb, nand_programmator.sch]
2020-06-26 Checked and updated Farnelss refs
    [nand_programmator.sch]
2020-06-26 Added HY27US08121B to chip database
    [nando_chip_db.csv]
2020-06-28 When reading BB marker, store it at the correct buffer offset
    [nand_programmer.c]
2020-06-30 Added read spare area command for HY27US08121B
    [nando_chip_db.csv]
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2020-08-30 Fixed Farnell Refs for LEDs
    [nand_programmator.sch]
2020-08-30 Adjusted PCB size to 48x41 mm size
    [nand_programmator.kicad_pcb]
2020-08-30 PCB: updated capacitor values from schematic
    [nand_programmator.kicad_pcb]
2020-08-30 The footprints moved to local library
    [nand_programmator.kicad_pcb, nand_programmator.sch]
2020-08-30 Fixed Crystal description
    [nand_programmator.kicad_pcb, nand_programmator.sch]
2020-08-30 Updated revision of PCB and schematic
    [nand_programmator.kicad_pcb, nand_programmator.sch]
2020-09-05 Connected SPI pins to adapter
    [nand_programmator.kicad_pcb, nand_programmator.sch]
2020-09-06 PCB: routed noise suppression capacitors and differential pairs
    [nand_programmator.kicad_pcb]
2020-09-06 PCB: routed all connections
    [nand_programmator.kicad_pcb]
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2020-09-18 Schematic: quartz changed to more widespread part with Cl=18pF
    [nand_programmator.kicad_pcb, nand_programmator.sch]
2020-09-18 Added SOIC-8 adapter for AT45DB
    [adapter_soic8_solder.kicad_pcb, adapter_soic8_solder.sch]
2020-09-19 Schematic symbols copied to local library
    [nand_programmator.sch]
2020-09-19 PCB: changed gerber settings
    [adapter_soic8_solder.kicad_pcb, adapter_tsop48.kicad_pcb, adapter_tsop48_solder.kicad_pcb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]
2020-10-03 Fixed compilation for Qt 5.15.x: replace QString:sprintf by QString:asprintf
    [main_window.cpp]
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2020-10-11 Schematics rework. Reset pad added.
    [nand_programmator.kicad_pcb, nand_programmator.sch]
2020-10-18 add support for MT29F4G08ABAD
    [nando_chip_db.csv]
2020-10-18 fix: the ID did not print out stings in windows because 'asprintf' not suggest in qt5
    [main_window.cpp]
2020-10-18 fix: correcting MT29F4G08ABAD size from 32MBytes to 512MBytes
    [nando_chip_db.csv]
2020-11-18 add MX30LF2G18AC
    Macronix MX30LF2G18AC (256MB)
    [nando_chip_db.csv]
2020-11-22 Added K9G8G08U0A to chip database
    [nando_chip_db.csv]
2020-11-22 Fixed duplicate ID bytes for HY27US08121B
    [nando_chip_db.csv]
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2020-11-28 Added SPI chip database
    [nando_parallel_chip_db.csv, nando_spi_chip_db.csv]
2020-11-28 Fixed presentation of chip ID in range 0x0-0xf
    [main_window.cpp]
2020-11-28 Chip detection for SPI
    [nando_spi_chip_db.csv]
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2020-11-28 Skip BB check for SPI
    [fsmc_nand.c, nand_programmer.c, spi_flash.c]
2020-11-29 Use correct page address offset for SPI block erase
    [spi_flash.c]
2020-11-29 Fixed SPI address endianess
    [spi_flash.c]
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2020-12-05 Moved parallel flash configuration to its class
    [nando_spi_chip_db.csv]
2020-12-05 Fixed hex presentation of SPI chip parameters
2020-12-05 Moved BB offset parameter to optimise parsing
    [nando_parallel_chip_db.csv]
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2020-12-06 Configure SPI BUSY bit number and active state from host app
    [nando_spi_chip_db.csv]
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2020-12-19 Fixed async serial port close
    [main_window.cpp]
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2020-12-19 Fixed logs from another thread
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2020-12-20 Fixed timer reset on close
2020-12-20 Fixed buffer dump font on windows
    [main_window.cpp]
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2021-01-17 Do not use 5th ID for Micron since it depends on configuration
    [nando_parallel_chip_db.csv]
2021-02-14 Reset NAND on init
    [fsmc_nand.c]
2021-03-13 Show read buffer on UI without skipped bad blocks
    [main_window.cpp]
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2021-04-16 Fixed Cypress chip names
    [nando_parallel_chip_db.csv]
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2022-07-10 Revert "A file instead of a read/write buffer."
    This reverts commit a9f956a48cfe9872ae552495005f34640596ff87.
    [main_window.cpp, settings.h]
2022-07-16 A file instead of a read/write buffer.
    This reverts commit bcd4fe78550b635cac71b700f0552230367fc985.
    [main_window.cpp, settings.h]
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2022-08-04 Qt: Settings dialog: Fix current port select in ListBox.
2022-11-02 Firmware: Fixed calculate size for big NAND chips.
    [nand_programmer.c]
2023-02-26 Qt: Add flash work range support.
    Qt: Fix progress in part mode
    [main_window.cpp]
2023-03-01 Qt: fix compile error when ODR check enabled.
    when two structs with the same name, the linker many be confused. when LTO
    is enabled, ODR checked is required.
    ```
    parallel_chip_info.cpp:36:3: error: type ‘struct Conf’ violates the C++ One Definition Rule [-Werror=odr]
    36 | } Conf;
    | ^
    spi_chip_info.cpp:20:3: note: a different type is defined in another translation unit
    20 | } Conf;
    ```
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2023-03-18 Revert "upgrade project files to kicad version 6.0.11"
    This reverts commit 6c6c989fefeeef77173a4749b3826cd3583d0fba.
    [adapter_soic8_solder.kicad_pcb, adapter_soic8_solder.kicad_sch, adapter_tsop48.kicad_pcb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]
2023-05-14 Aligned size of BB, write ack and error responses
    [nand_programmer.c]
2023-05-14 firmware: Fix typos in debug messages. Unused include in main.c
    [main.c, nand_programmer.c]
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2024-12-21 Feature/add macos support (#88)
    * improvements for MACOS build
    * add initial code for nor flash
    * add initial code for nor flash
    * nor flash init
    * Add cmaker support for QT compilation on Macos
    Set default baudrate to 115200 to avoid issue with MacOS launch
    * workaround macos native menubar issue
    * build macos bundle
    * Fix low baudrate issue in OSX
    * nor flash stuff
    * draft cmaker file and improve makefiles
    * fix some issues
    * fix some issues
    * fix some issues
    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
    [nando_parallel_chip_db.csv, nando_spi_chip_db.csv]
2024-12-28 Revert "Feature/add macos support (#88)" (#89)
    This reverts commit a011ffc99e41fa05f59329d9b10f6789cf7bd718.
    [nando_parallel_chip_db.csv, nando_spi_chip_db.csv]

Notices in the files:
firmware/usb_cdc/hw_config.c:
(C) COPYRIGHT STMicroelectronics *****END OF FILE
